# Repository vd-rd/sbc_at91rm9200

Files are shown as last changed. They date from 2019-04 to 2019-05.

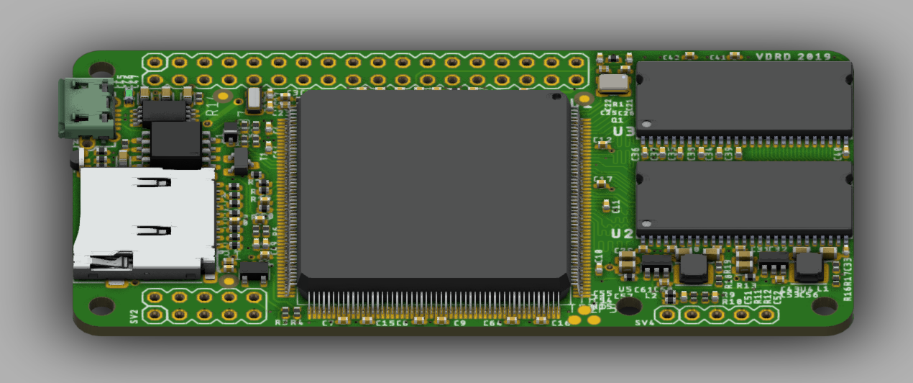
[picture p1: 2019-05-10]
assets/front_ang.PNG

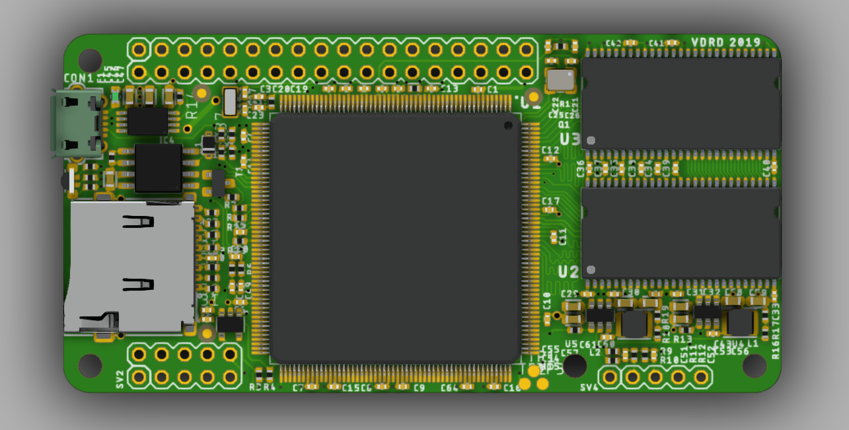
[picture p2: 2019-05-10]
assets/top.PNG

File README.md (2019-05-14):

## Overview
This module, based on Microchip (Atmel) AT91RM9200 microprocessor, is intended as a learning exercise in designing an embedded Linux development board suitable for IoT and other applications.
 All the board resources and documentation are open source and can be contributed to.
 Detailed documentation, as well as resources used can be found in the [docs](docs) and [resources](resources) folders.

### Key features
 * Low price for an embedded Linux system;
 * Medium difficulty to assemble at home;
 * Documented features and mainline support in kernel.

### Specifications
  * AT91RM9200 microprocessor @ 190MHz;
  * 64MB SDRAM @ 90MHz;
  * 2MB DataFlash memory for U-boot and environment storage;
  * MicroSD connector for RootFS and user storage;
  * Expansion headers with common functions available (USART, SPI, I2C, RMII, USB Host, etc.);
  * USB client connector.

### Todo
 * build the board
 * gather the components
 * test the board
 * build optimised U-Boot and Busybox

### Resources
You can find all necesary information to build or evaluate the module here:
   - [View layout and schematic](https://cadlab.io/project/1679) ;
   - [View 3D board render](https://a360.co/2G43pcl);
   - [Fabrication files](https://github.com/vd-rd/sbc_at91rm9200/releases);

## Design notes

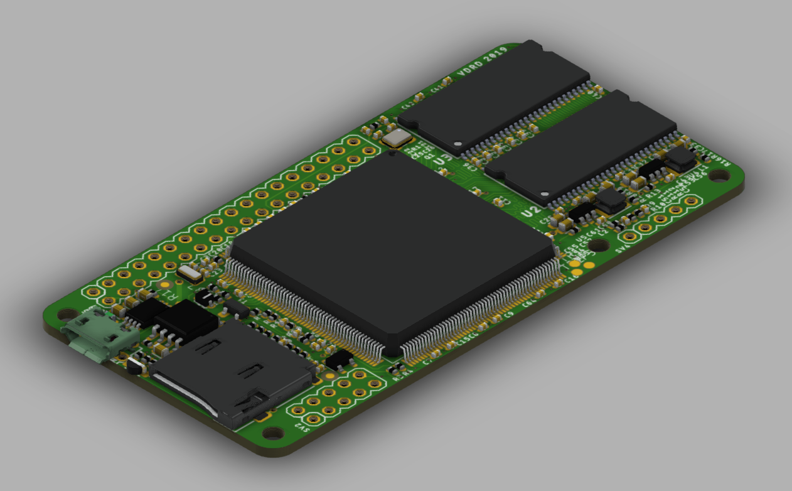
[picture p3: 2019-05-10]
assets/persp.PNG

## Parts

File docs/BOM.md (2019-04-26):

## Revision 0.1 BOM

| # | Part count | Part desciptor | Part name | Part type | Part description | Observations |
| --- | --- | --- |--- | --- | --- | --- |
| 1 | 1 | U1 | AT91RM9200-QU-002 | IC |
| 2 | 2 | U2, U3 | W9825G6KH-6 | IC |
| 3 | 2 | U4, U5 | AP65211A | IC |
| 4 | 1 | U6 | STM1831 | IC |
| 5 | 1 | U7 | AT45DB161 | IC |
| 6 | 1 | CON1 | 10118194 | CONN | Micro USB receptacle |
| 7 | 1 | Q1 |  3225-18.432M-SR | CRYSTAL | 18.432 MHz Crystal |
| 8 | 1 | Q2 | CFPX-217-NHT | CRYSTAL | 32.768 kHz Crystal |
| 9 | 2 | L1, L2 | DJNR3015-4R7 | INDUCTOR | | Actual value TBD |
| 10 | 1 | CON2 | 112J-TXAR | CONN | MicroSD connector |

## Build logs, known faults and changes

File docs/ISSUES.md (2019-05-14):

## Known issues
The processor has some known issues, outlined in the errata section. The most important ones are:
 * The MCI controller (manages the SD Card) 
 * The EBI controller (manages the SDRAM inteface)
 
 ## Hardware limitations
  * SDRAM devices larger than 256Mb can't be used
  * SD Cards maximum supported size should be determined
  * Code on the NVM memory must be loaded outside the device for now ( no method for in system programming)

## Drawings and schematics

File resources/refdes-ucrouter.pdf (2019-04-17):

# AT91RM9200 208-PQFP

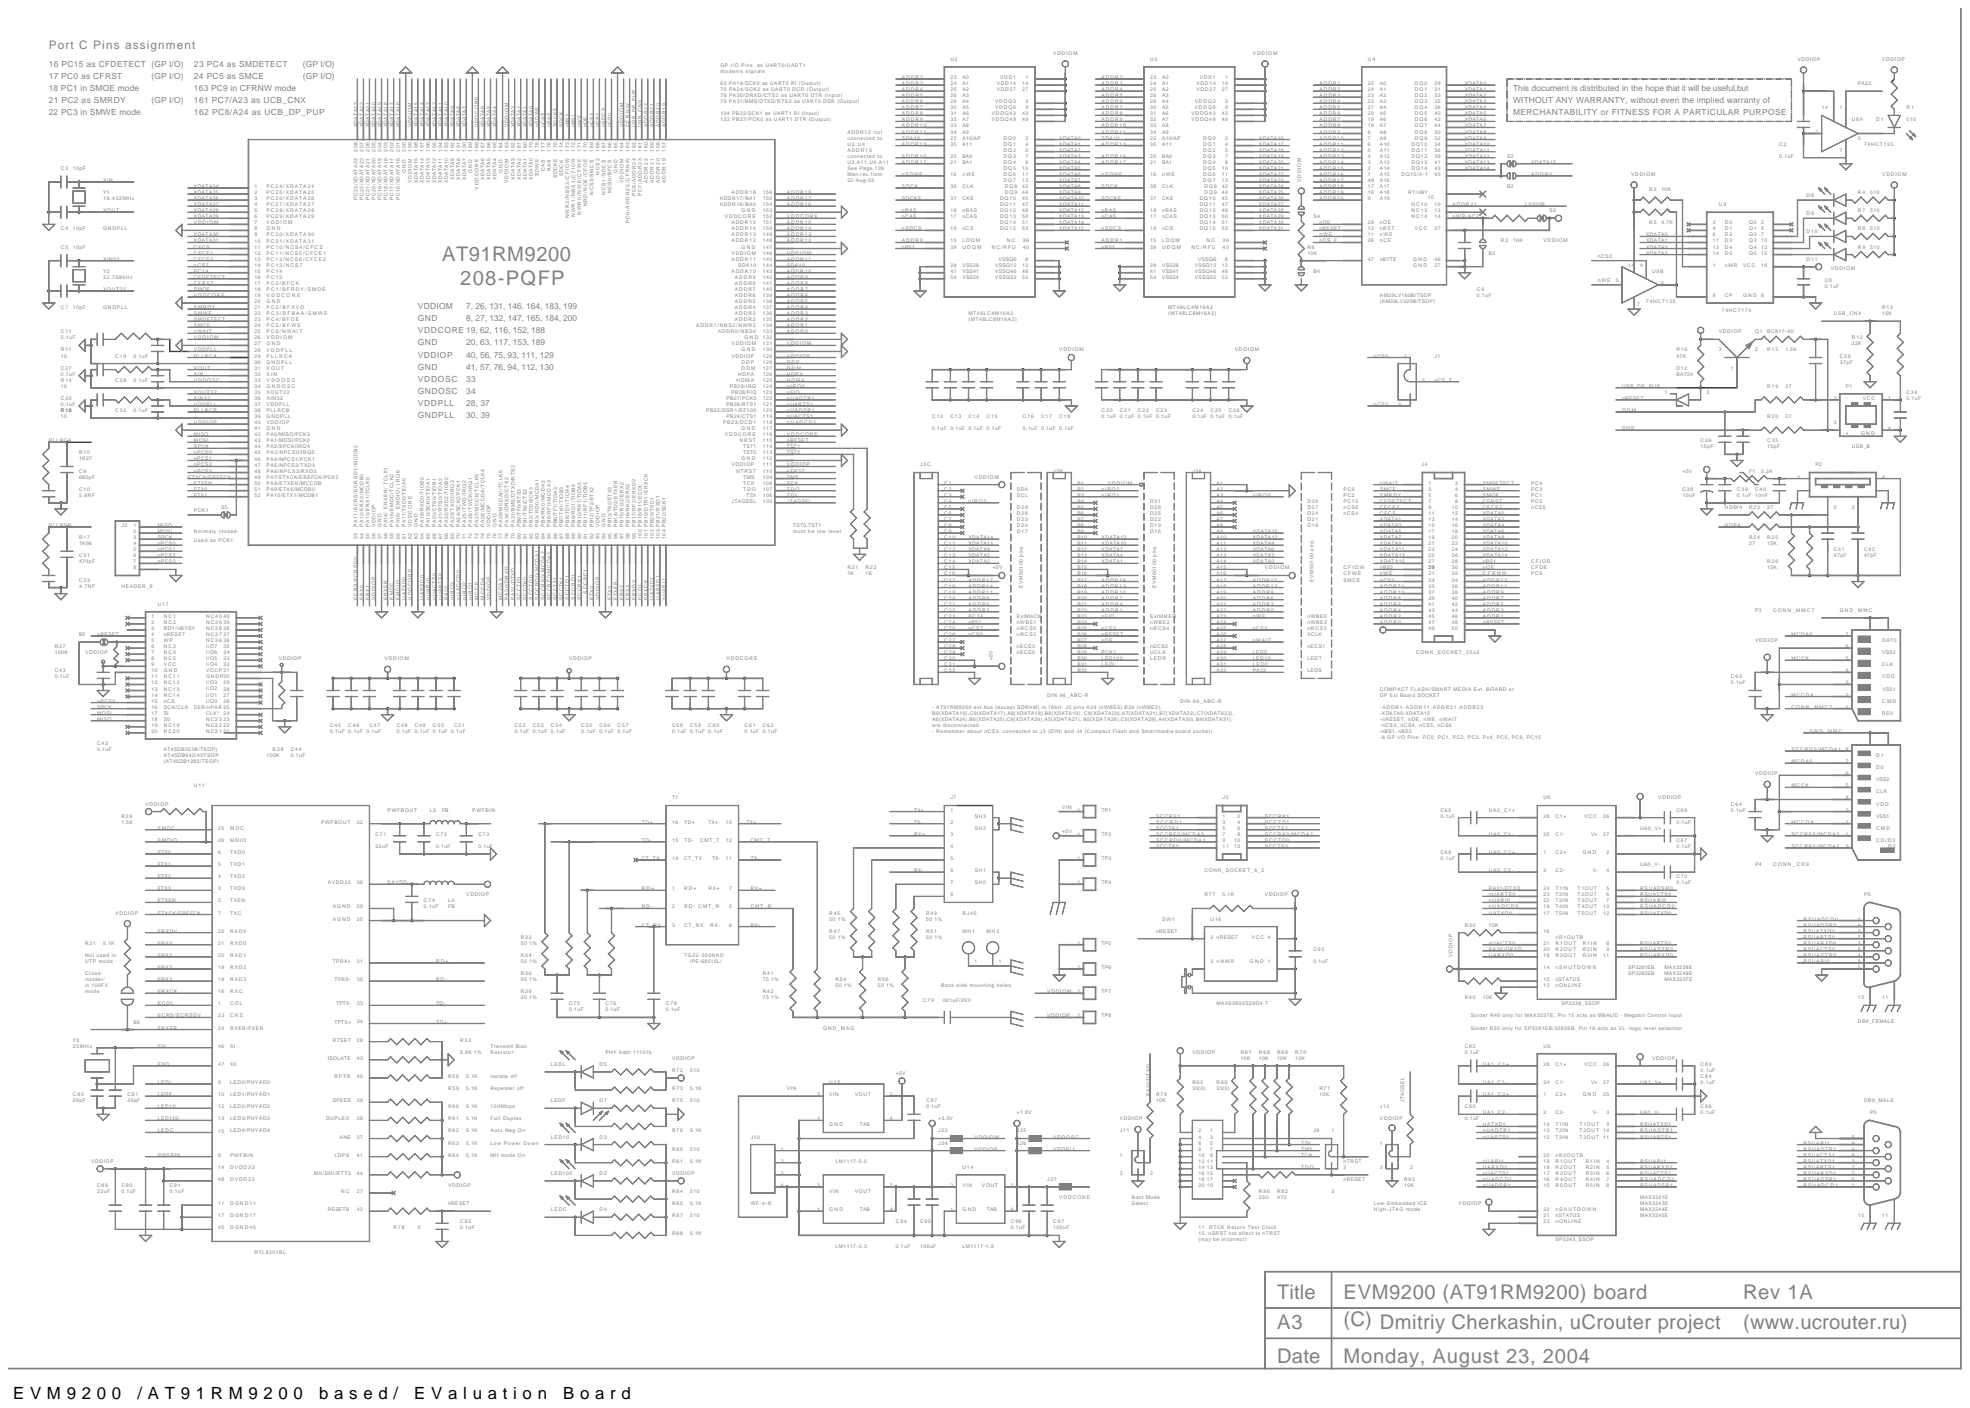
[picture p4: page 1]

65 PA19/SCK0 as UART0 RI (Output)
70 PA24/SCK2 as UART0 DCD (Output)
78 PA30/DRXD/CTS2 as UART0 DTR (Input)
79 PA31/BMS/DTXD/RTS2 as UART0 DSR (Output)

This document is distributed in the hope that it will be useful,but
WITHOUT ANY WARRANTY, without even the implied warranty of

MERCHANTABILITY or FITNESS FOR A PARTICULAR PURPOSE

TST0,TST1
must be low level

COMPACT FLASH/SMART MEDIA Ext. BOARD or
GP Ext Board SOCKET

- AT91RM9200 ext.bus (except SDRAM) is 16bit: J3 pins A24 (nWBE3),B24 (nWBE2),
B9(XDATA16),C9(XDATA17),A8(XDATA18),B8(XDATA19), C8(XDATA20),A7(XDATA21),B7(XDATA22),C7(XDATA23),
A6(XDATA24),B6(XDATA25),C6(XDATA26),A5(XDATA27), B5(XDATA28),C5(XDATA29),A4(XDATA30),B4(XDATA31),
are disconnected
- Remember about nCS3, connected to J3 (DIN) and J4 (Compact Flash and Smartmedia board socket)

TX+CMT_T TX- RX+ CMT_R RX- TD+ TD- CT_TX RD+ RD- CT_RX

Back side mounting holes.

Solder R40 only for MAX3237E, Pin 15 acts as MBAUD - Megabit Control Input

Solder R30 only for SP3281EB/3282EB, Pin 16 acts as VL -logic level selection

11. RTCK Return Test Clock
15. nSRST not affect to nTRST
(may be incorrect)

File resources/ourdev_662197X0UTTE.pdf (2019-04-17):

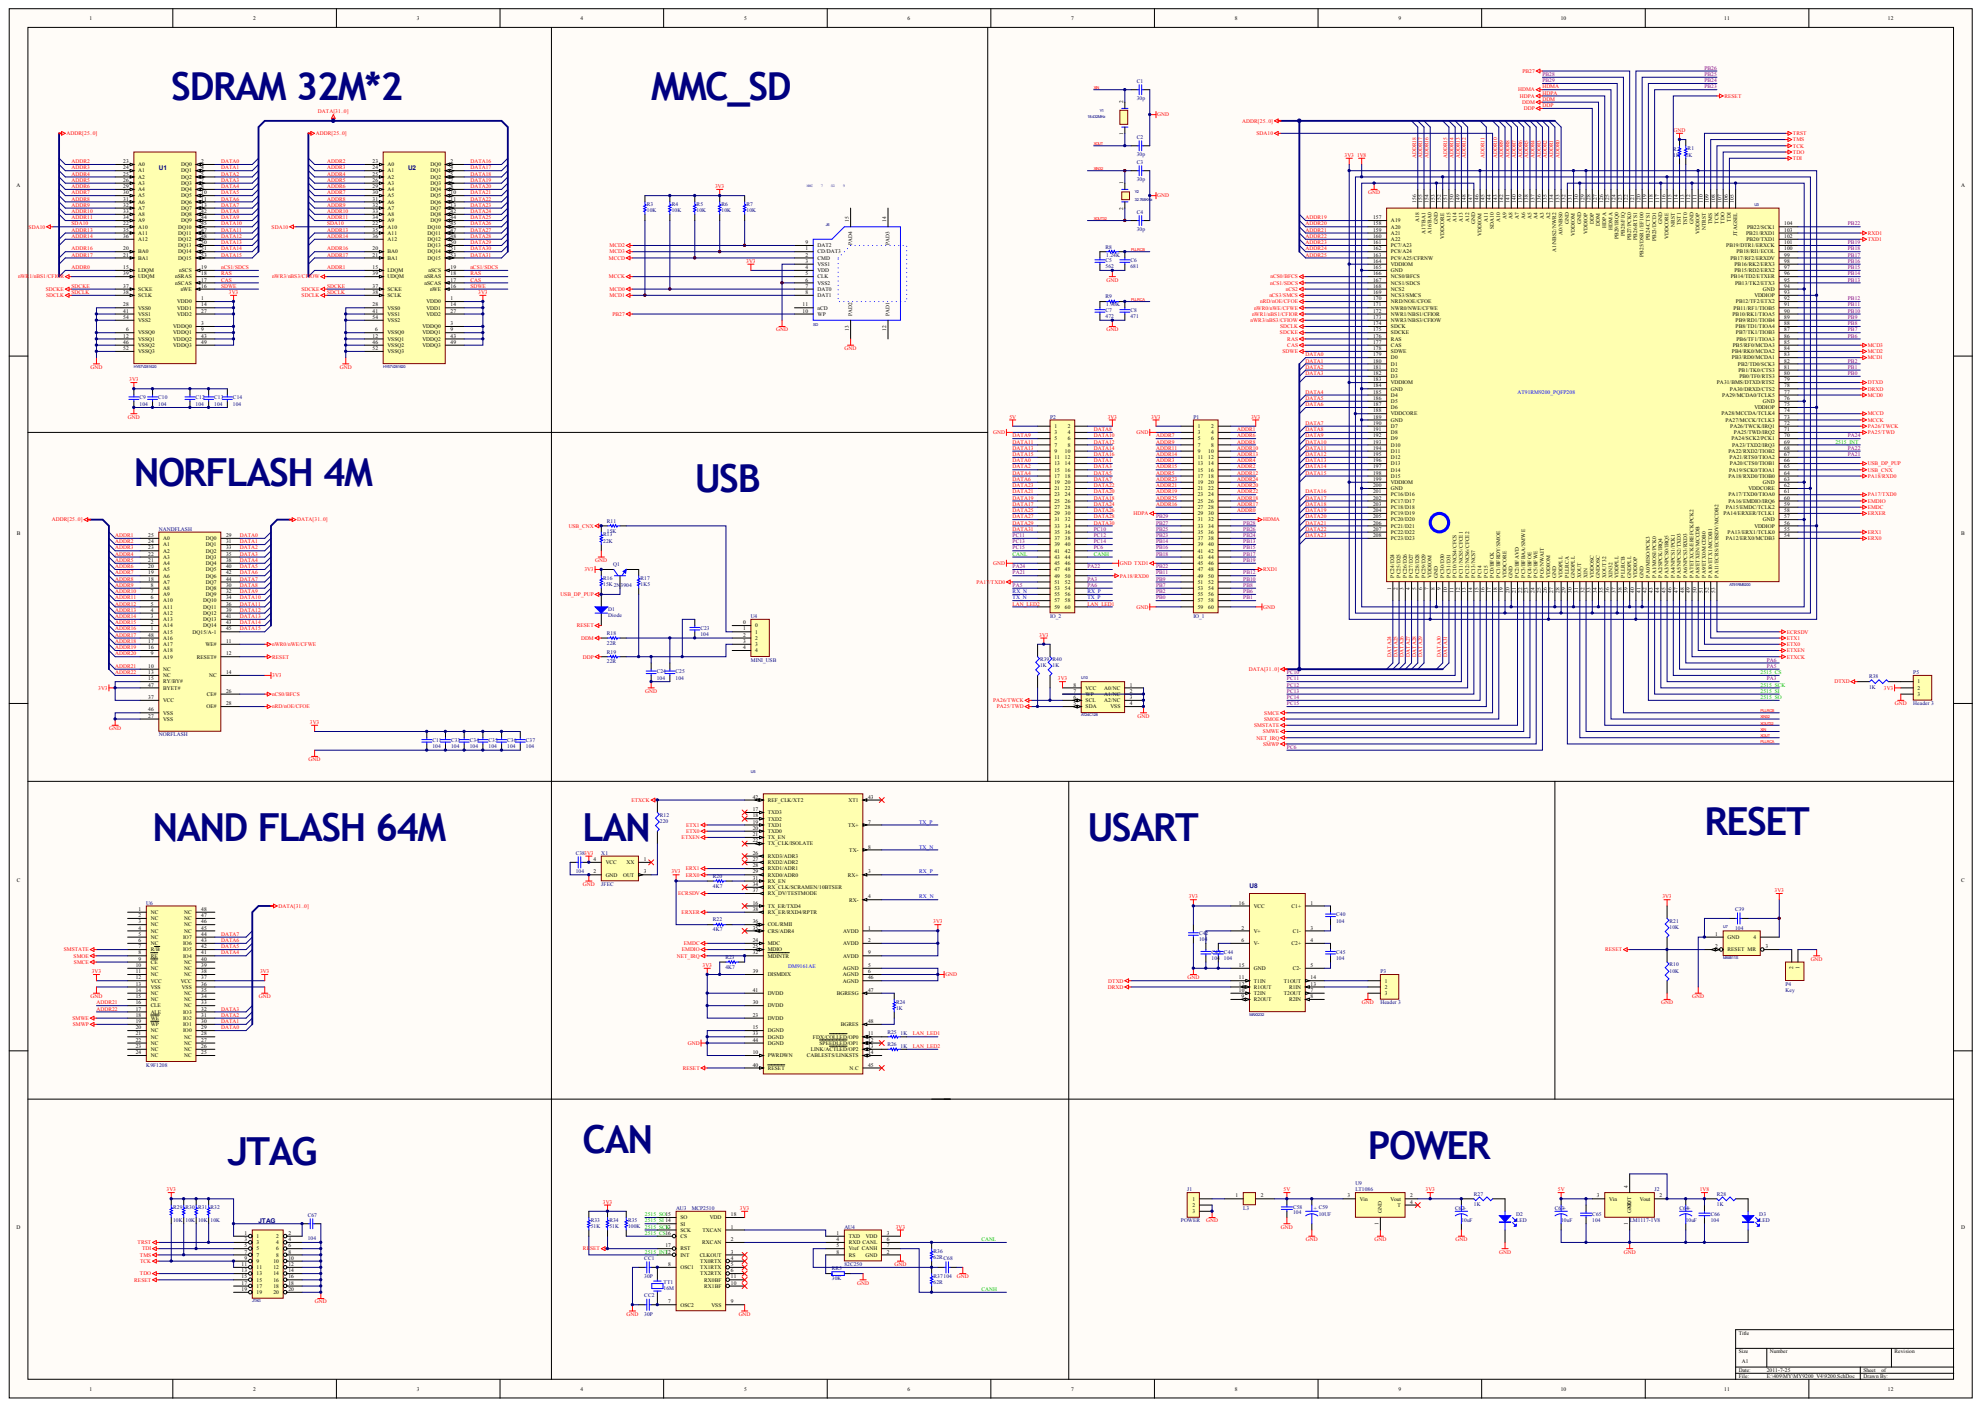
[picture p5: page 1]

HDMA | PB23
HDPA DDM | GND

JTAGSEL 105 TDI 106 TDO 107 TCK 108 TMS 109 NTRST 110 VDDIOP 111 GND 112 TST0 113 TST1 114 NRST 115 VDDCORE 116 GND 117 PB23/DCD1 118 PB24/CTS1 119 PB25/DSR1/EF100 120 PB26/RTS1 121 PB27/PCK0 122 PB28/FIQ 123 PB29/IRQ0 124 HDMA 125 HDPA 126 DDM 127 DDP 128 VDDIOP 129 GND 130 VDDIOM 131 GND 132 A0/NBS0 133 A1/NBS2/NWR2 134 A2 135 A3 136 A4 137 A5 138 A6 139 A7 140 A8 141 A9 142 A10 143 SDA10 144 A11 145 VDDIOM 146 GND 147 A12 148 A13 149 A14 150 A15 151 VDDCORE 152 GND 153 A16/BA0 154 A17/BA1 155 A18 156

DATA3 DATA4 | D3 182 VDDIOM 183

DATA5 | D5 186

Bill of Materials | <Parameter Title not found>
Source Data From: | 9200.PrjPCB
Project: | | 9200.PrjPCB
Variant: | | None
Creation Date: 2011-7-25 | 17:10:50
Print Date: | 40749 | 40749.71593
Footprint | Comment | LibRef | Designator | Description | Quantity
MCP2515 | MCP2510 | MCP2510 | AU3 | | 1
SO-8 | 82C250 | 82C250 | AU4 | | 1
0603 | Cap | Cap | C1, C2, C3, C4, C5, C6, C7, C8, C67 | Capacitor | 9
0603 | 104 | Cap | C9, C10, C11, C12, C13, C14, C23, C24,
| | | C25, C33, C34, C35, C36, C37, C38, C39,
| | | C40, C42, C43, C44, C45, C58, C65, C66,
| | | C68 | Capacitor | 25
TAN_CAP | 10UF | CAPACITOR
| | POL | C59, C62, C63, C64 | Capacitor | 4
0603 | 30P | CAP | CC1, CC2 | Capacitor | 2
1206 | Diode | Diode | D1 | Default Diode | 1
0805 | LED | LED | D2, D3 | | 2
POWER | POWER | CON3 | J1 | Connector | 1
SOT223 | LM1117-1V8 | LM1117-1V5 | J2 | | 1
SD_CARD | SD_MMC_CAR
| D2 | SD_MMC_CAR
| | D2 | J6 | | 1
FKV20SN | JTAG | MULTI_ICE | JTAG | | 1
L | Component_1 | Component_1 | L3 | | 1
NANDFLASH | NORFLASH | NORFLASH | NANDFLASH | | 1
IDC60 | IO_1 | Header 30X2 | P1 | Header, 30-Pin, Dual row | 1
IDC60 | IO_2 | Header 30X2 | P2 | Header, 30-Pin, Dual row | 1
con3 | Header 3 | Header 3 | P3, P5 | Header, 3-Pin | 2
KEY | Key | Header 2 | P4 | Header, 2-Pin | 1
SOT-23+ | 2N3904 | 2N3904 | Q1 | NPN General Purpose Amplifier | 1
0603 | Res1 | Res1 | R1, R2, R3, R4, R5, R6, R7, R8, R9, R11,
| | | R13, R16, R17, R18, R19, R20, R22, R23,
| | | R24, R25, R26, R29, R30, R31, R32 | Resistor | 25
0603 | 10K | RES1 | R10, R21 | | 2
0603 | 220 | RES1 | R12 | | 1
0603 | 1K | RES1 | R27, R28, R38, R39, R40 | | 5
0603 | 51K | Res1 | R33, R34 | Resistor | 2
0603 | 100K | Res1 | R35 | Resistor | 1
0603 | 62R | Res1 | R36, R37 | Resistor | 2
0603 | 30K | RESISTOR | RR5 | | 1
XTAL | 16M | CRYSTAL | TT1 | Crystal | 1
SDRAM | HY57V281620 | K4S561632C | U1, U2 | | 2
9200 | AT91RM9200 | AT91RM9200P
| | Q208_0 | U3 | | 1
USB_DEVIC E | MINI_USB | MINI_USB | U4 | | 1
DM9161 | DM9161AE | DM9161E_3 | U5 | | 1
NANDFLASH | K9F1208 | NAND_FLASH | U6 | | 1
MAX811S | MAX811S | UD215_0 | U7 | | 1
MAX232 | MAX3232 | max232_1 | U8 | | 1
LTC1086 | LT1086 | LM1117-1V5 | U9 | 1A LOW DROPOUT VOLTAGE
| | | | REGULATOR | 1
SO-8 | AT24C128 | CAT24WC128_0 | U10 | | 1
JFEC | JFEC | JFEC | X1 | | 1
CRYSTAL | 18.432MHz | XTAL3_0 | Y1 | | 1
32768 | 32.768KHz | XTAL1_0 | Y2 | | 1
| | | | | 110
Approved | | Notes

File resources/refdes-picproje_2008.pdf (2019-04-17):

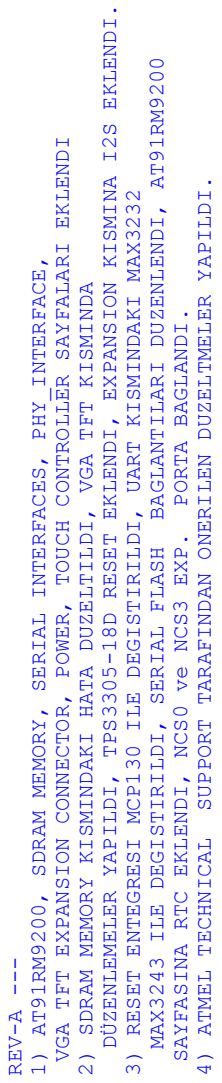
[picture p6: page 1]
Title; 00_REVISION HISTORY A; ARM9SBC; 1 11 Wednesday, February 06, 2008; REV-A ---

Size Document Number Rev

ERDAL T. --- GOKTUG C. --- PICPROJE 2008

Date: Sheet of

DÜZENLEMELER YAPILDI, TPS3305-18D RESET EKLENDI, EXPANSION KISMINA I2S EKLENDI.

MAX3243 ILE DEGISTIRILDI, SERIAL FLASH BAGLANTILARI DUZENLENDI, AT91RM9200

VGA TFT EXPANSION CONNECTOR, POWER, TOUCH CONTROLLER SAYFALARI EKLENDI

4) ATMEL TECHNICAL SUPPORT TARAFINDAN ONERILEN DUZELTMELER YAPILDI.

3) RESET ENTEGRESI MCP130 ILE DEGISTIRILDI, UART KISMINDAKI MAX3232

1) AT91RM9200, SDRAM MEMORY, SERIAL INTERFACES, PHY_INTERFACE,

2) SDRAM MEMORY KISMINDAKI HATA DUZELTILDI, VGA TFT KISMINDA

SAYFASINA RTC EKLENDI, NCS0 ve NCS3 EXP. PORTA BAGLANDI.

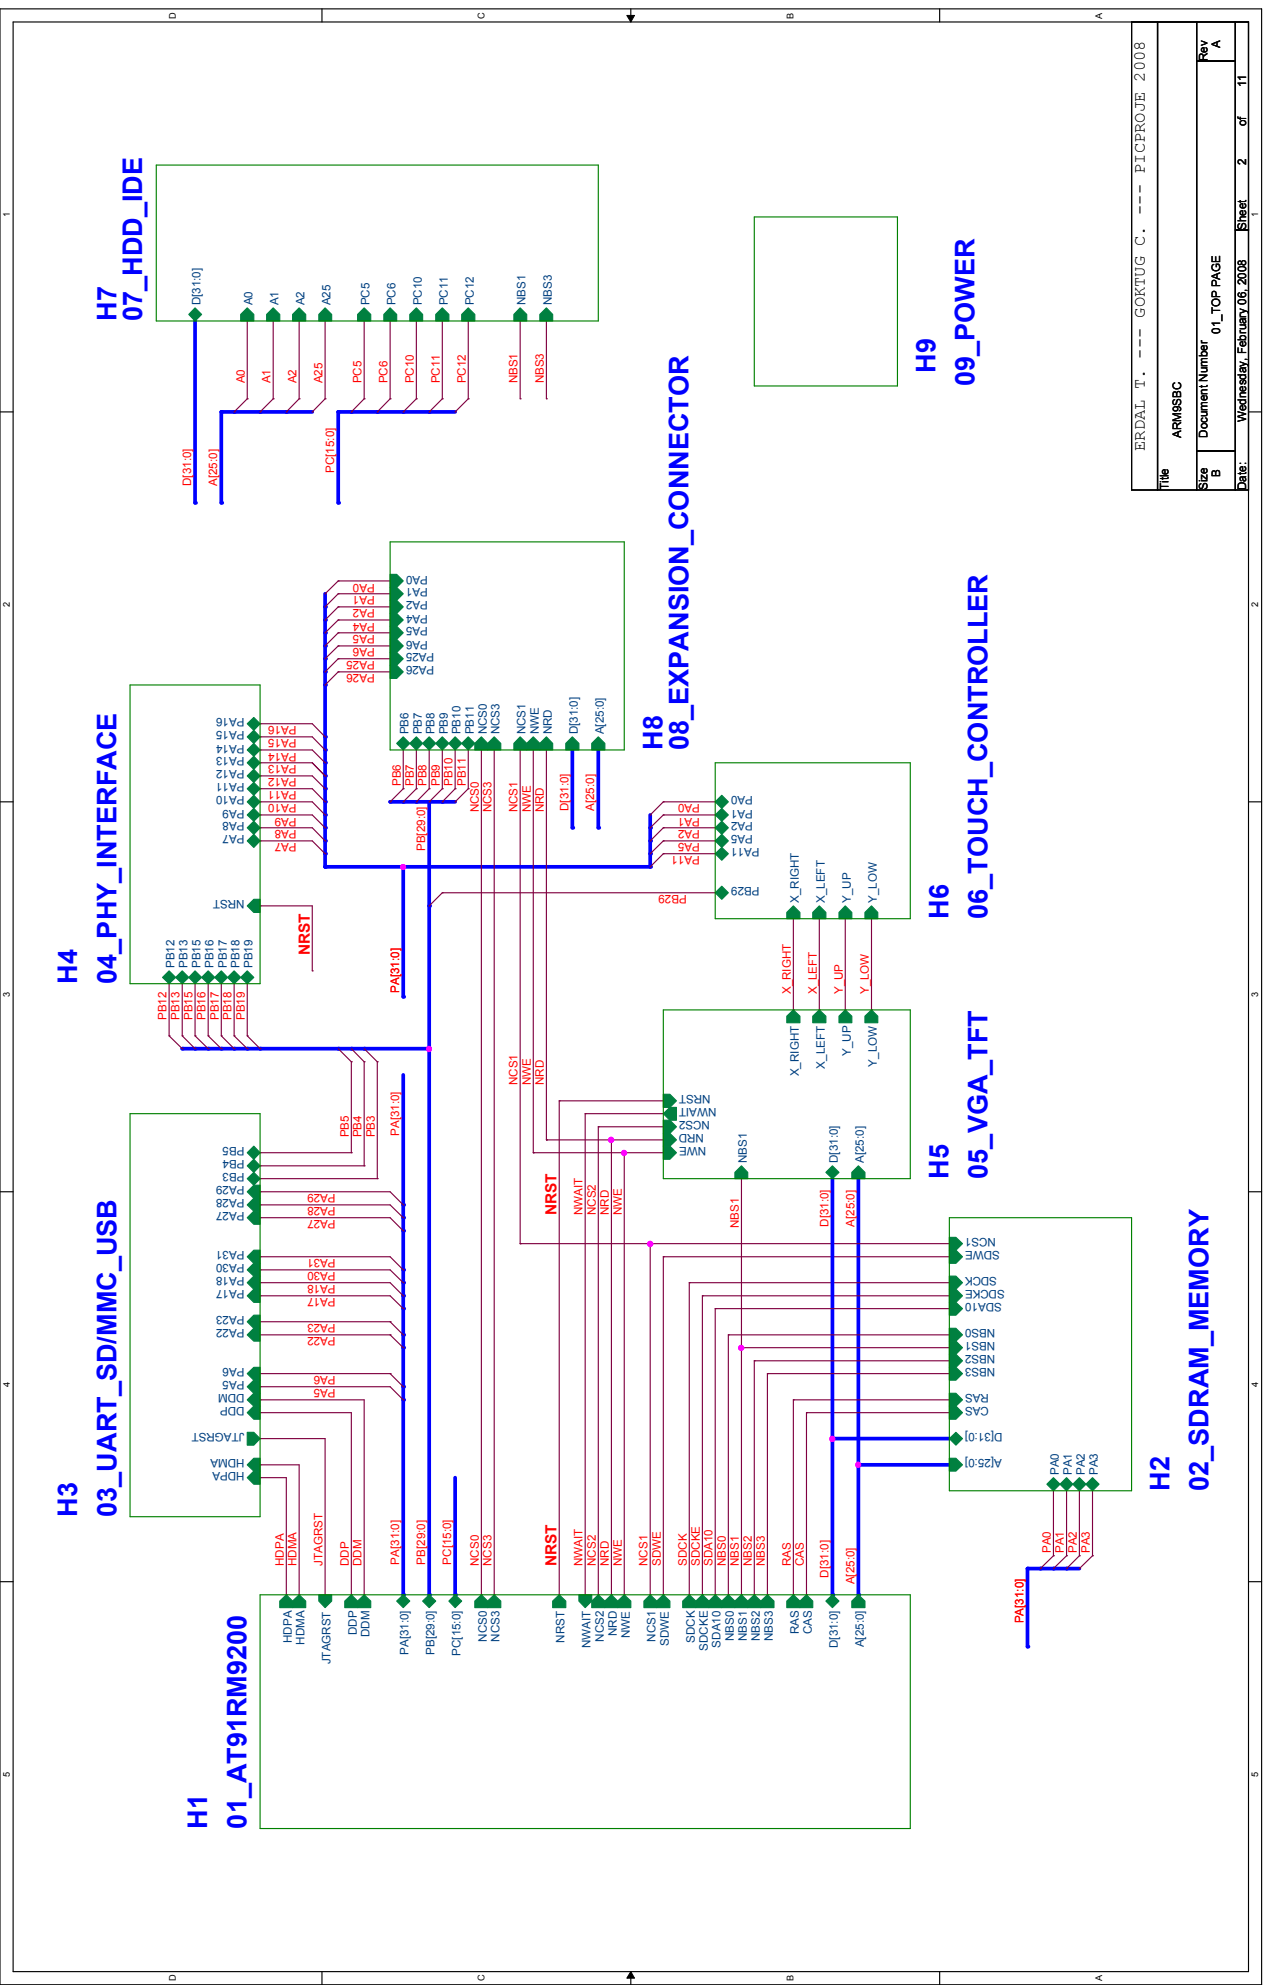
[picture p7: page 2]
HDPA; HDMA; SDWE; SDCK; SDCKE; NBS0; NBS1; RAS; CAS; JTAGRST; DDP; DDM; NRST NRST; NCS2 NCS2; NWAIT NWAIT; NCS1 NCS1; X_RIGHT; X_LEFT; Y_LOW; NCS1; NBS2; NBS3; SDA10; NRST; NRD NRD; NWE NWE; NCS0 NCS0; NCS3 NCS3; Title; 01_TOP PAGE A; ARM9SBC; 2 11 Wednesday, February 06, 2008; NCS2; NWE; NRD; NWAIT; NCS0; NCS3; 03_UART_SD/MMC_USB; 02_SDRAM_MEMORY; 05_VGA_TFT; 06_TOUCH_CONTROLLER; 04_PHY_INTERFACE; 08_EXPANSION_CONNECTOR; 09_POWER; 07_HDD_IDE

ERDAL T. --- GOKTUG C. --- PICPROJE 2008

Size Document Number Rev

Date: Sheet of

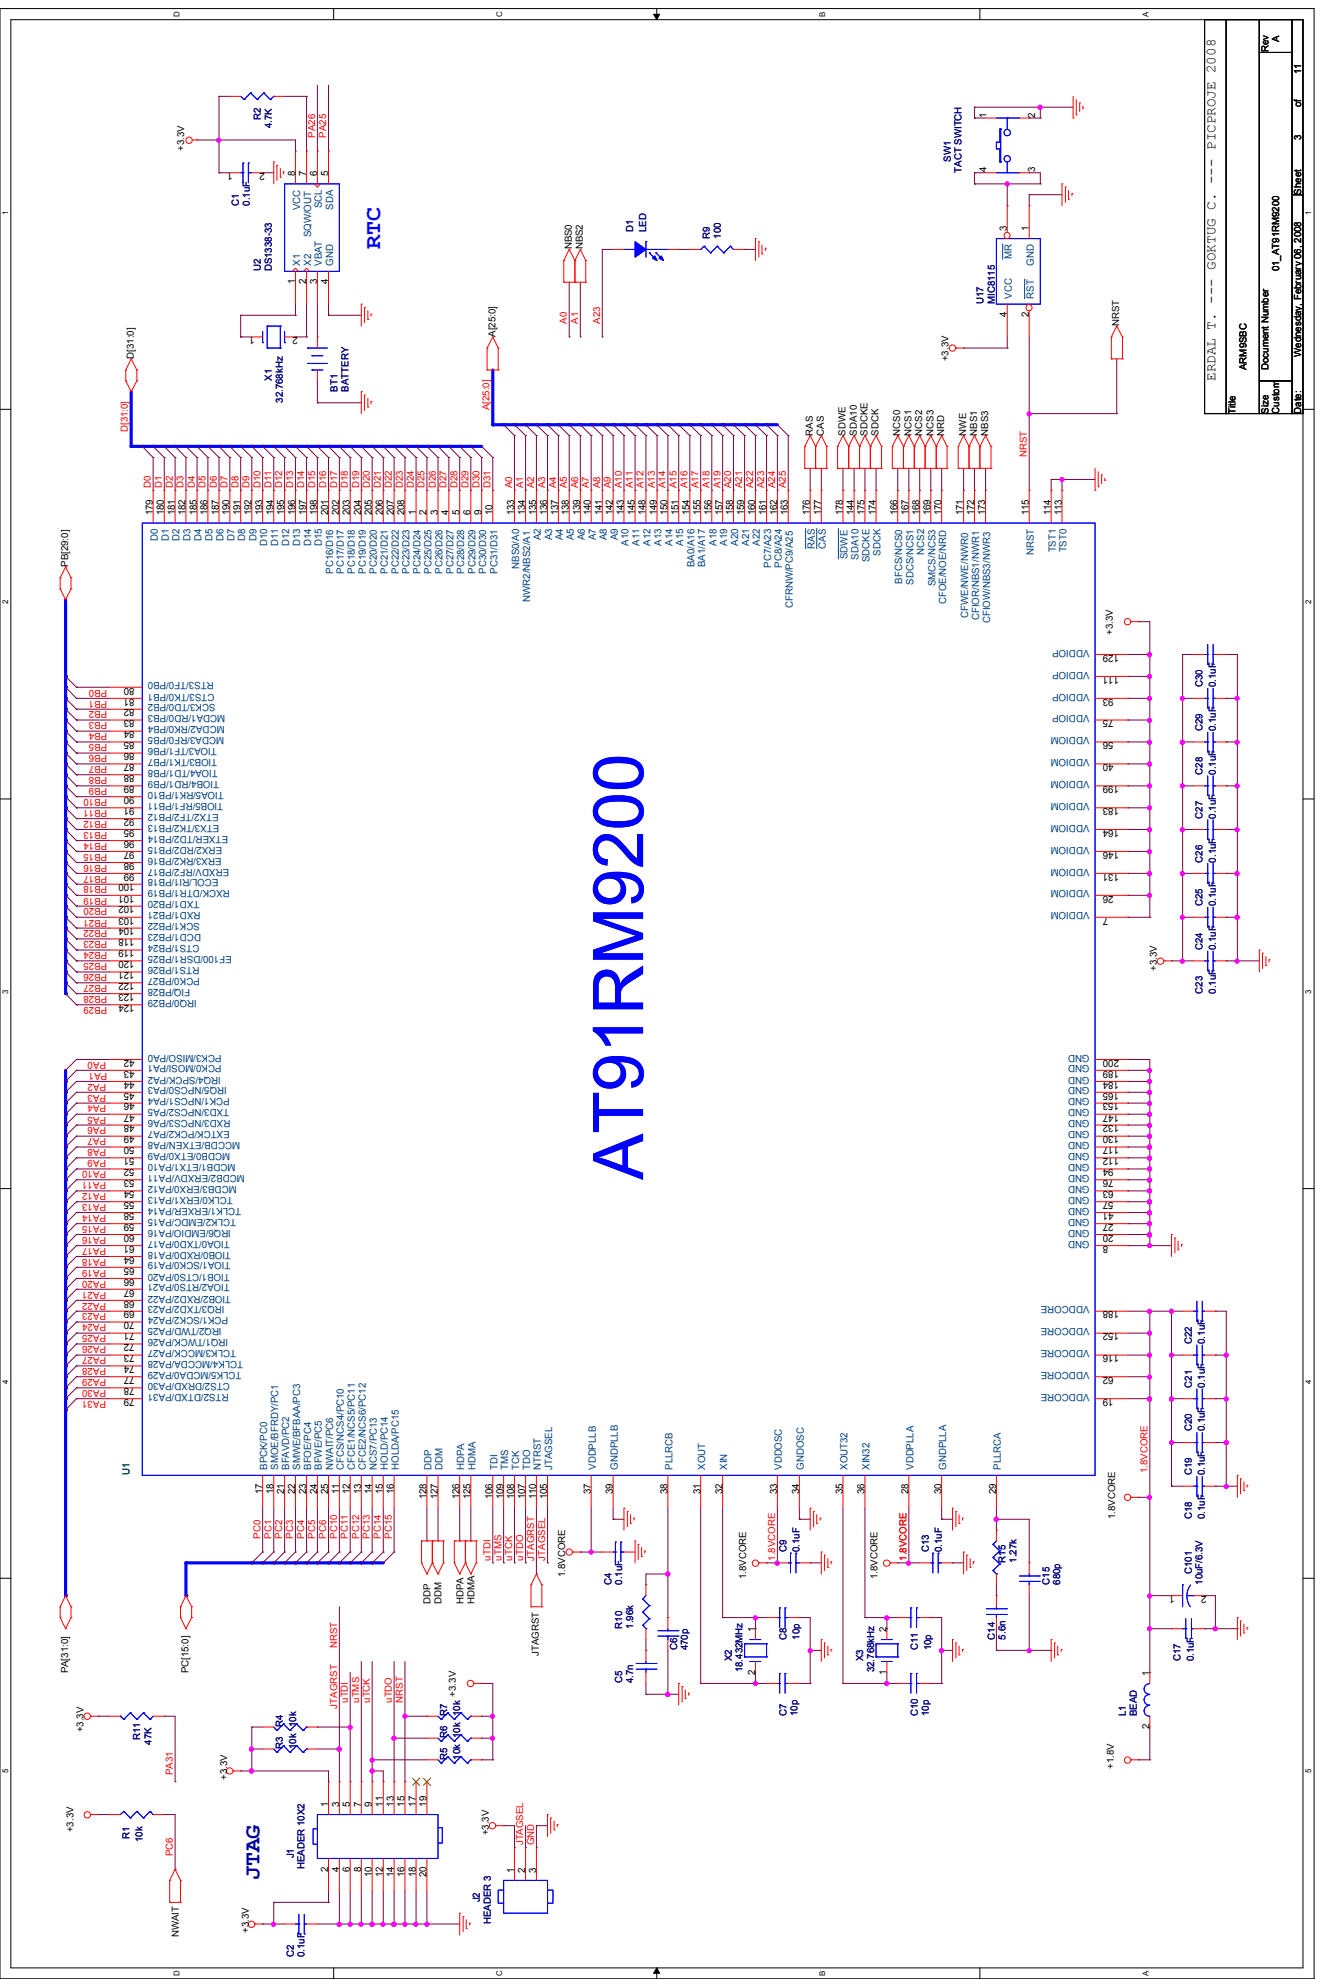
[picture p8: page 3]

Size Document Number Rev

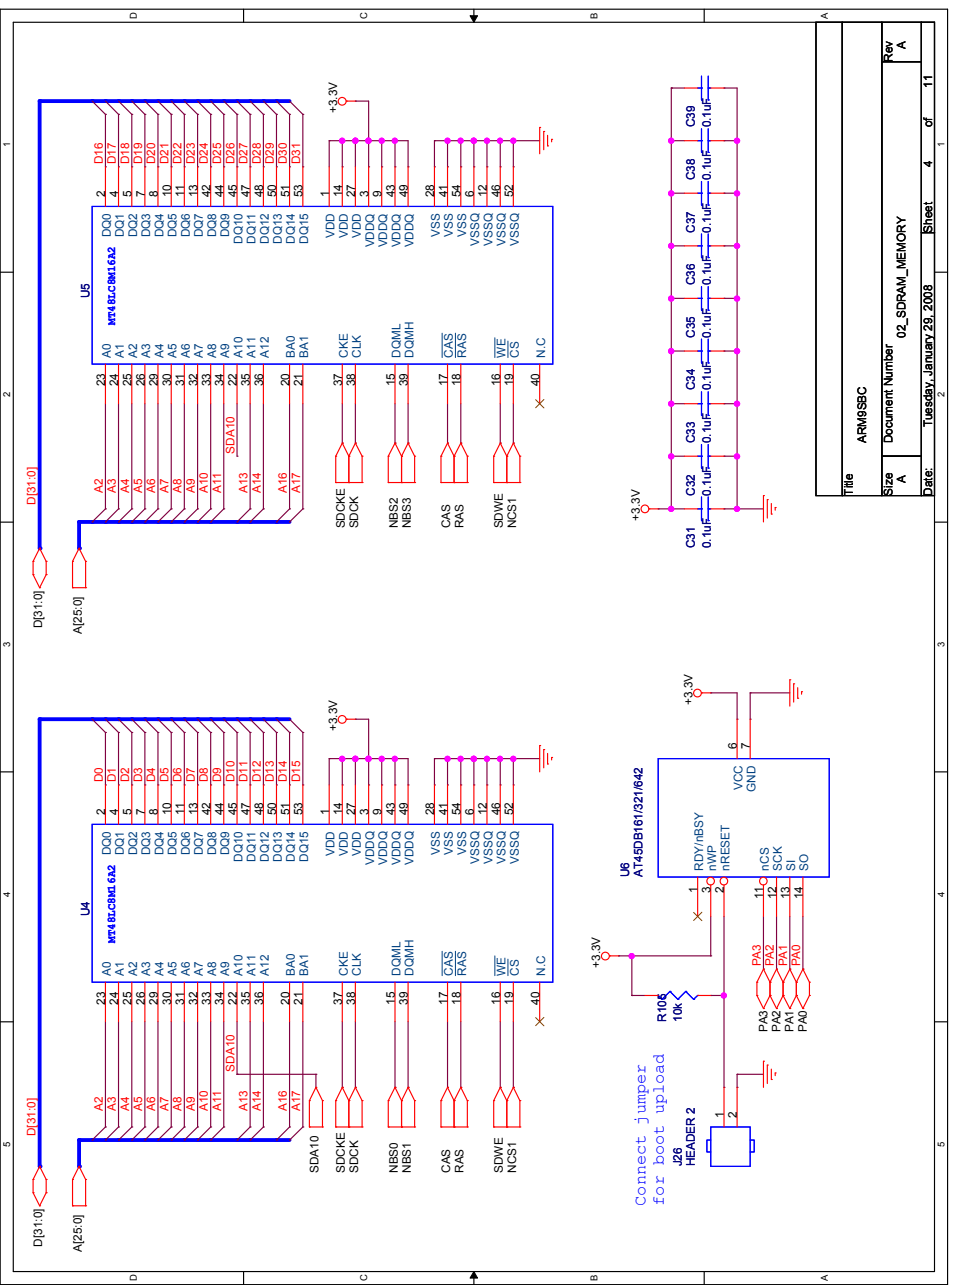
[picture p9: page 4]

Size Document Number Rev

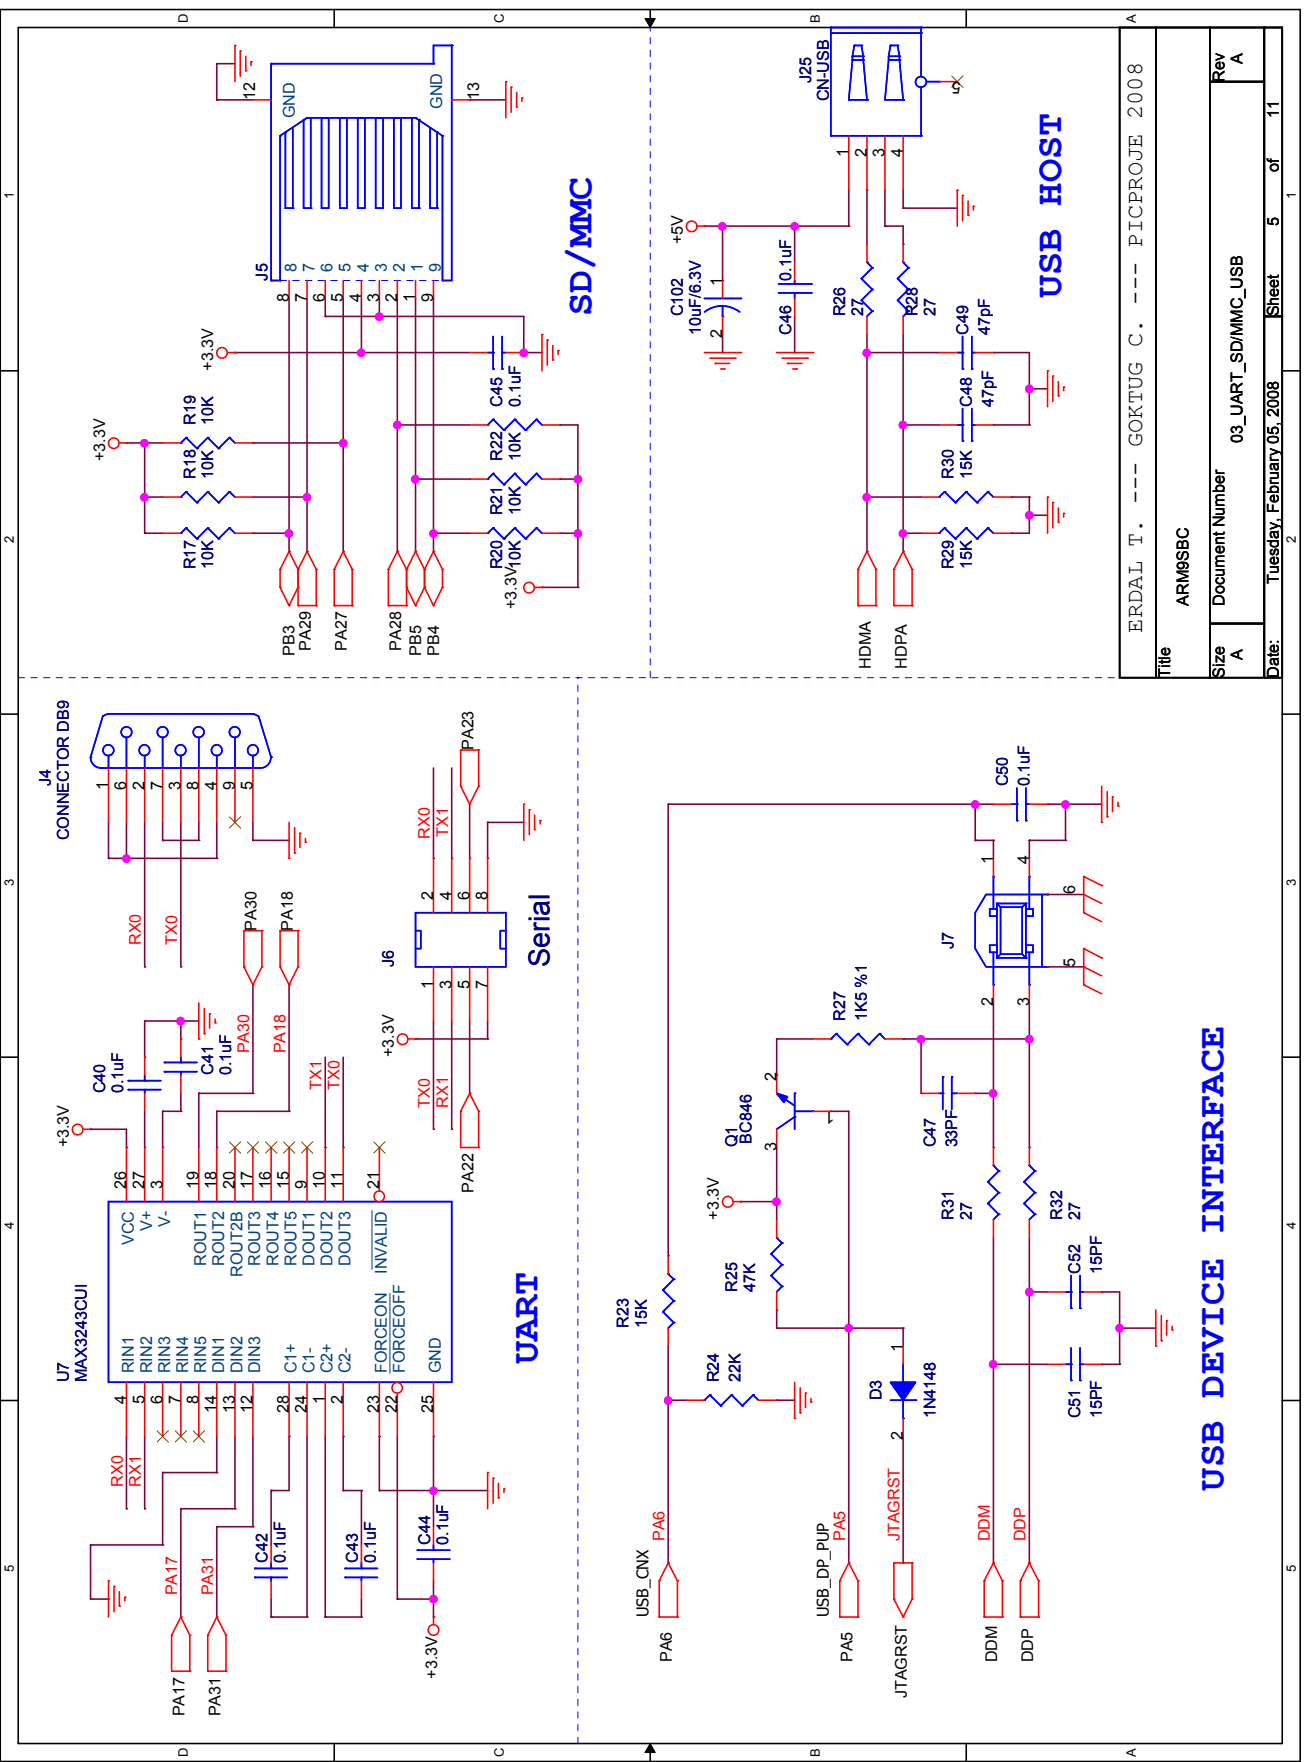
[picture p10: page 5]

Size Document Number Rev

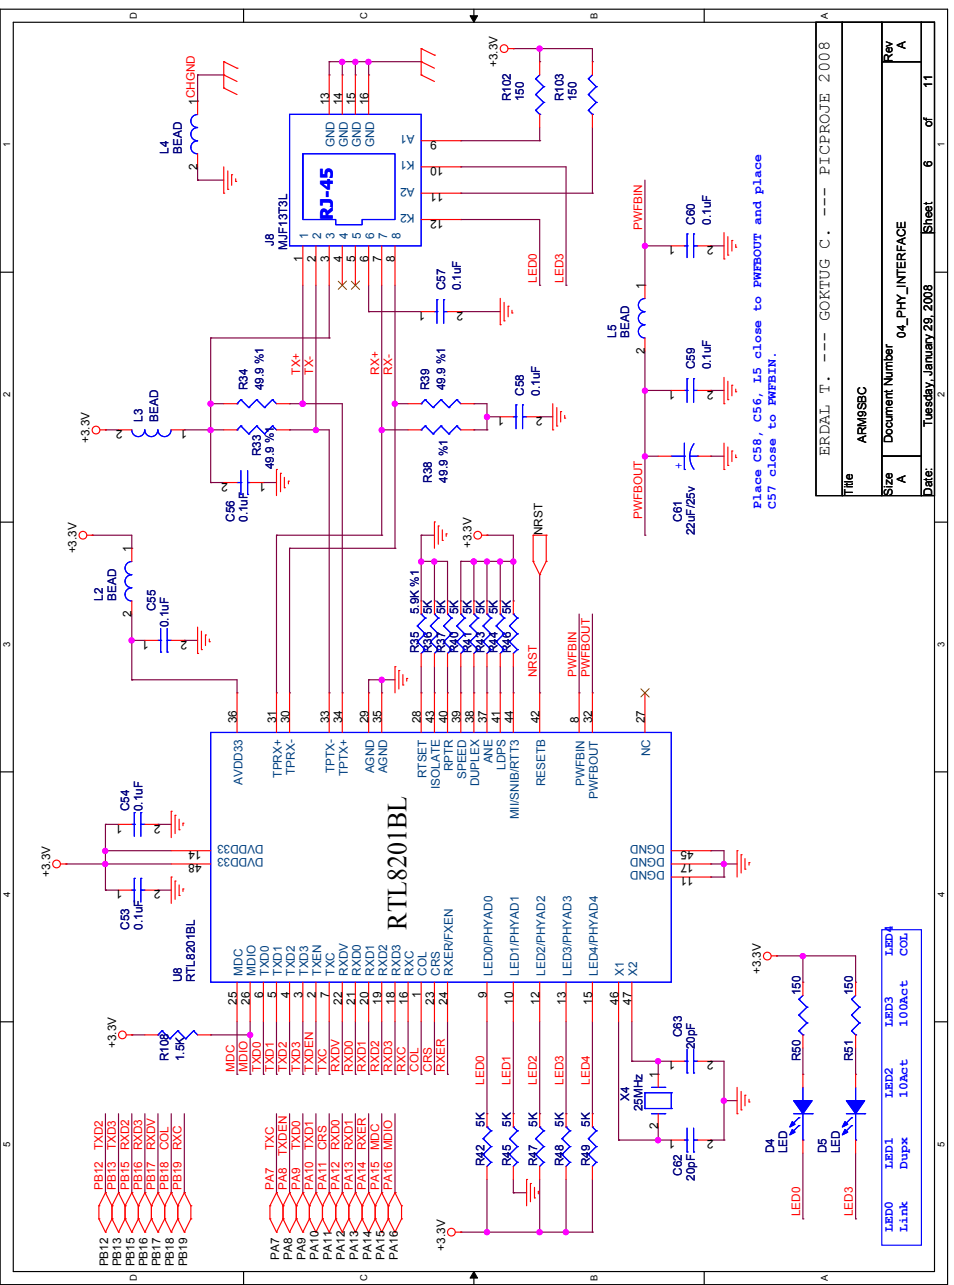
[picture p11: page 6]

Size Document Number Rev

CHGND MDC TXD0 TXD1 TXD2 TXD3 TXDEN TXC RXDV RXD0 RXD1 RXD2 RXD3

Place C58, C56, L5 close to PWFBOUT and place

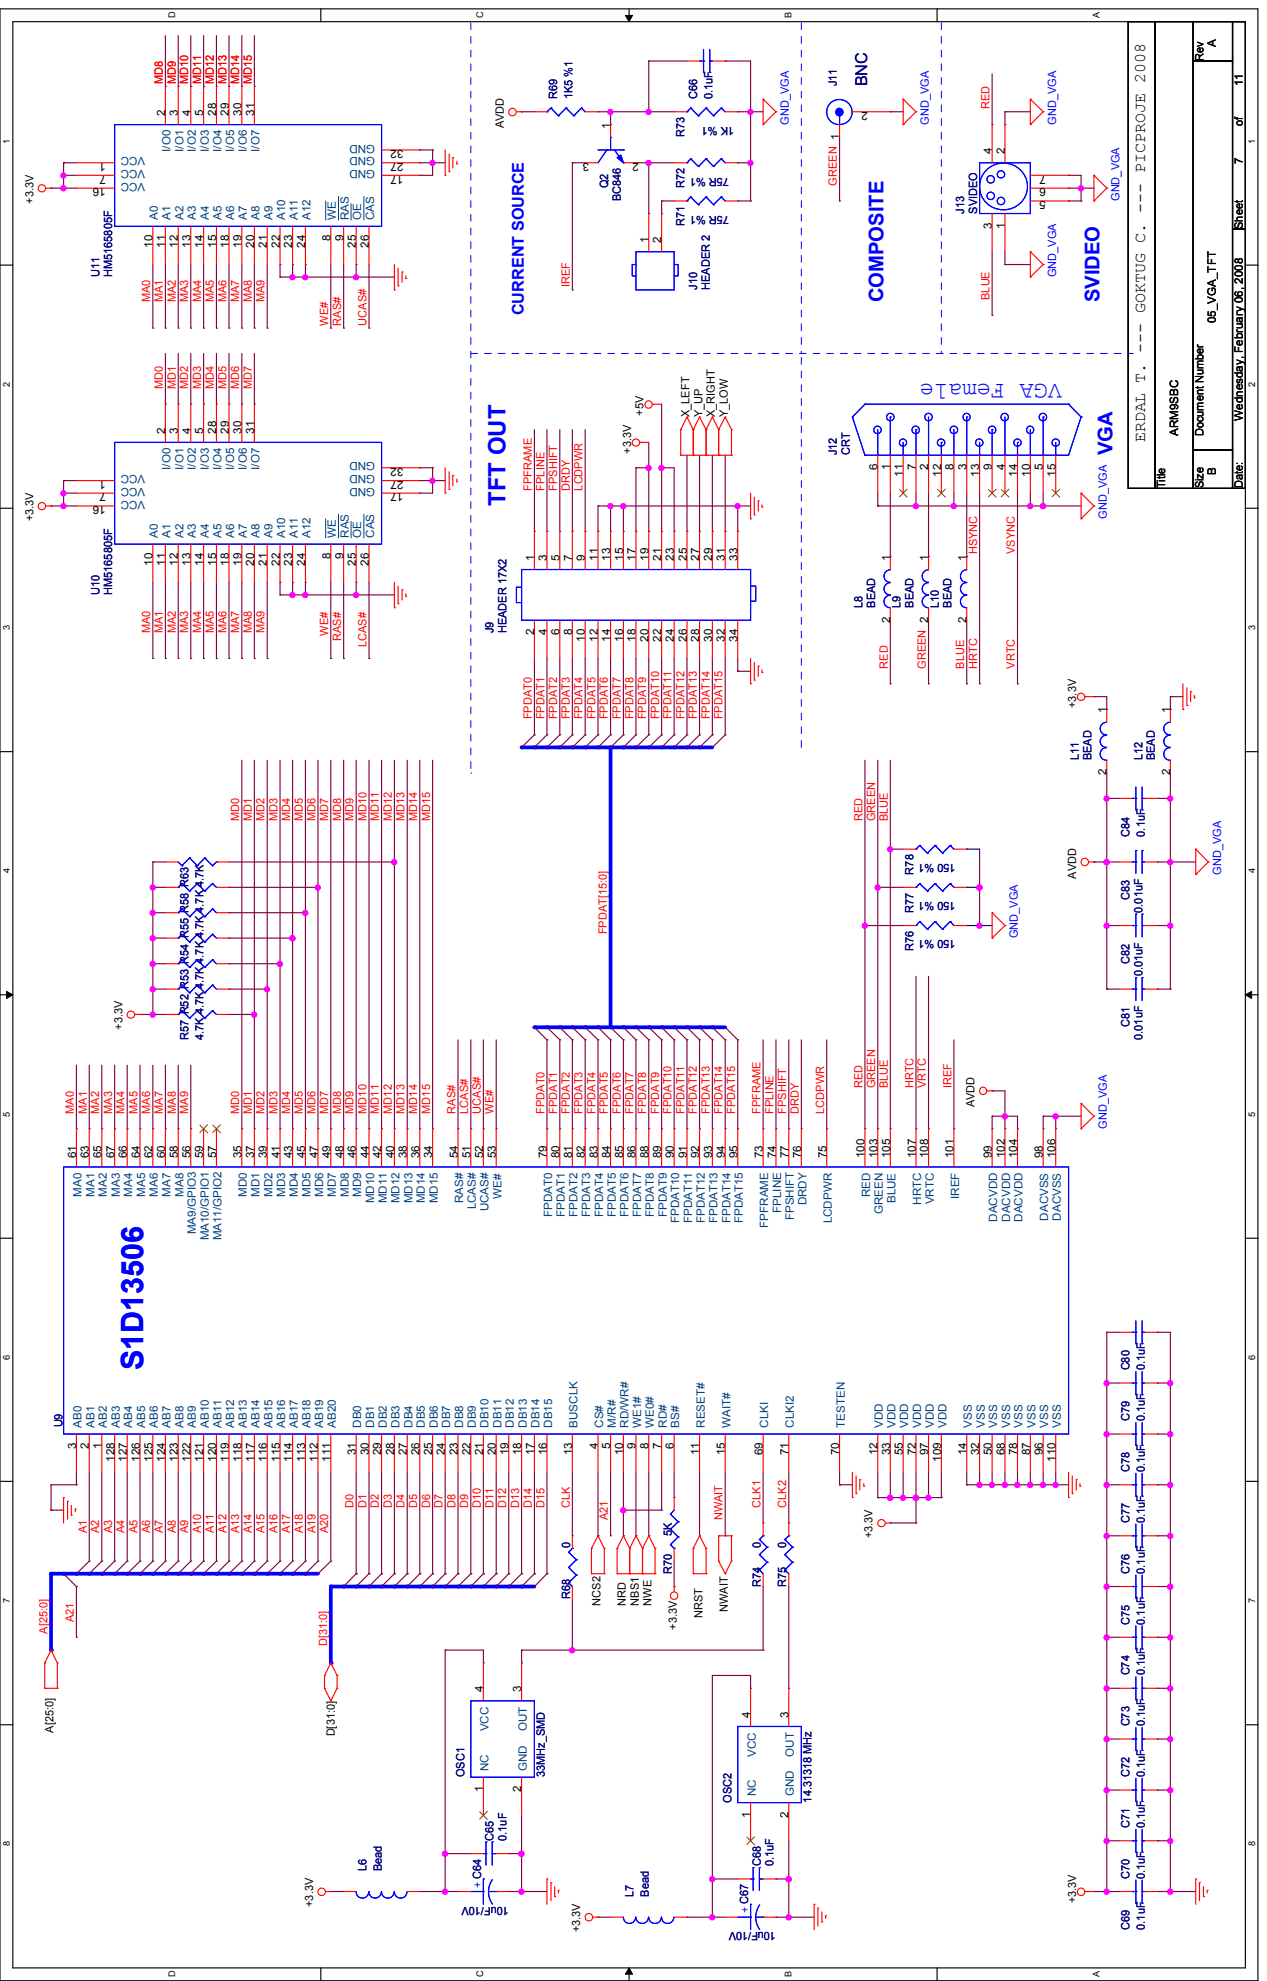
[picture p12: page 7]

Size Document Number Rev

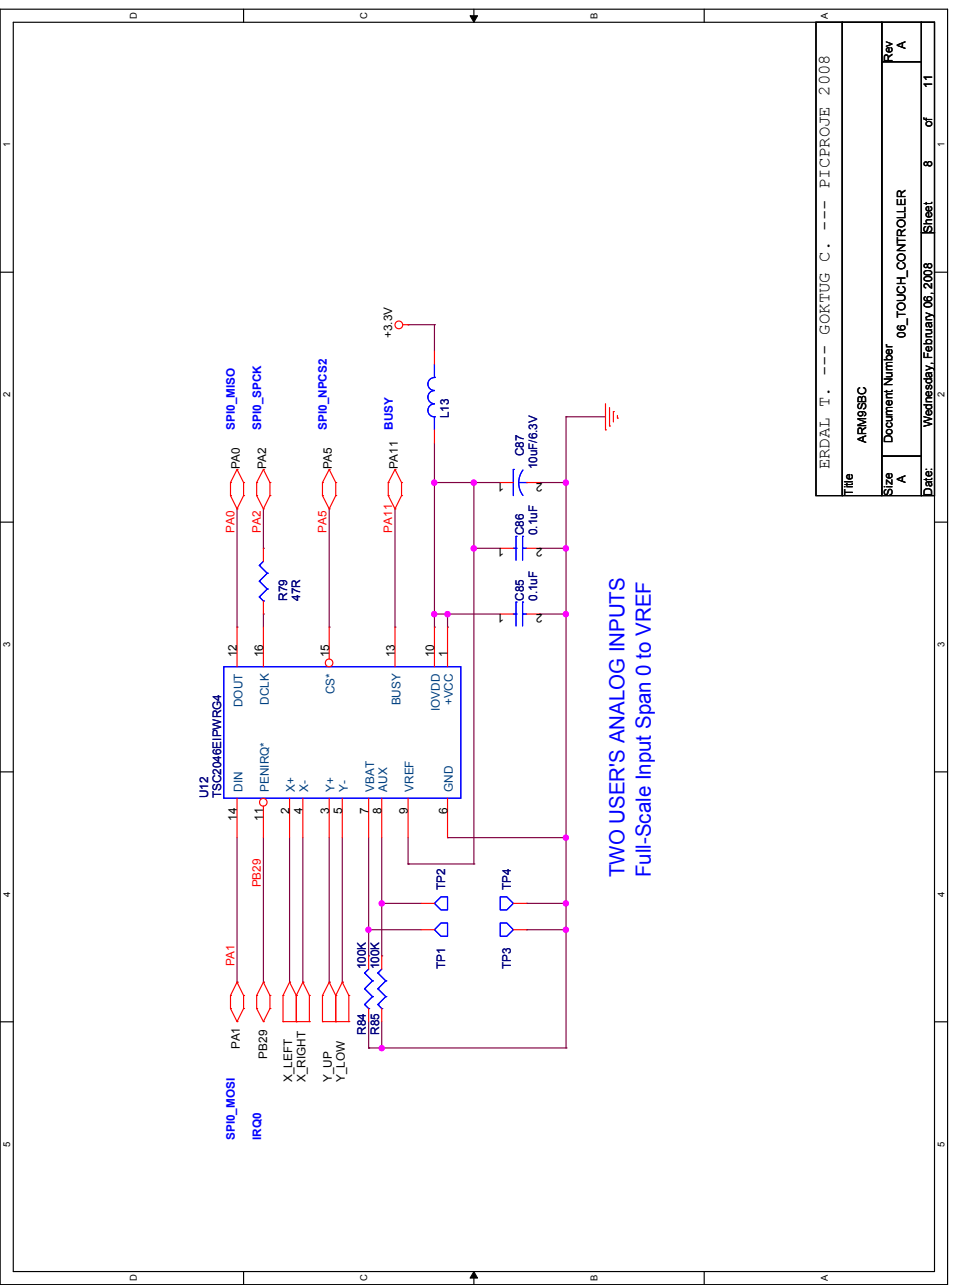
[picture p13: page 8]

Size Document Number Rev

TWO USER'S ANALOG INPUTS

Full-Scale Input Span 0 to VREF

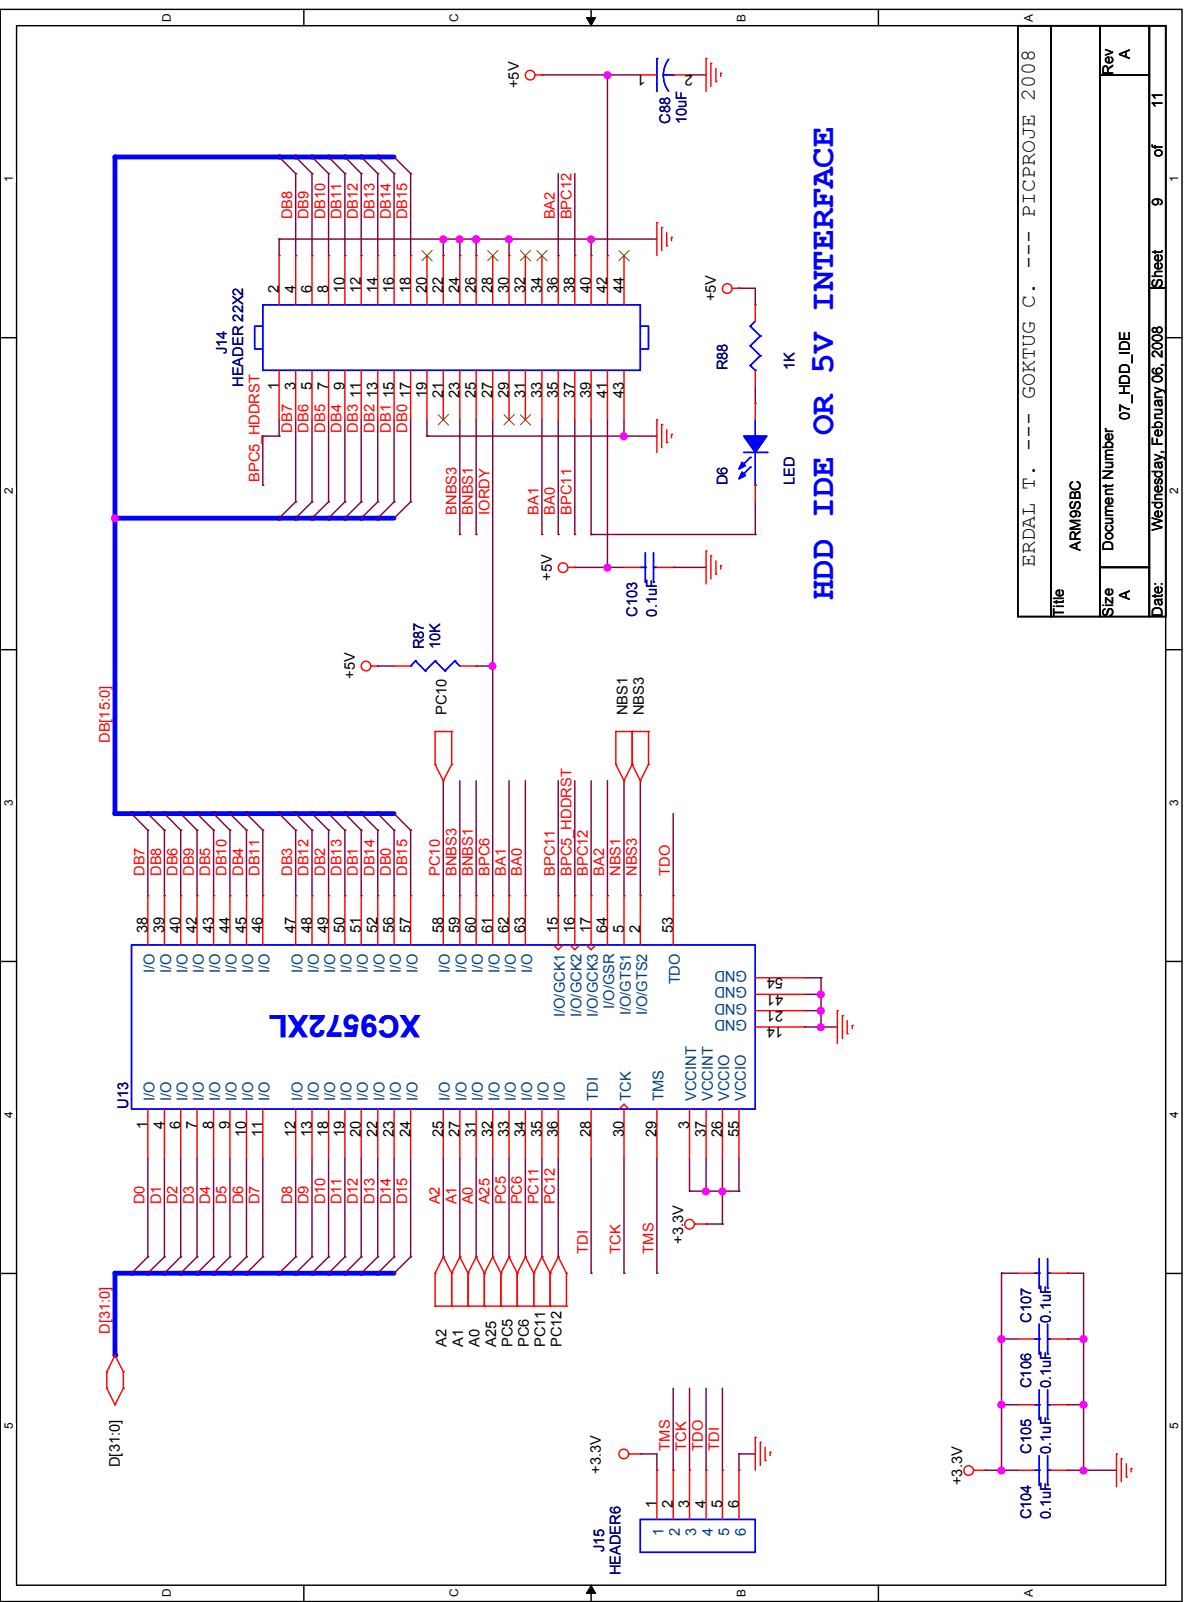
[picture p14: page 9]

Size Document Number Rev

HDD IDE OR 5V INTERFACE

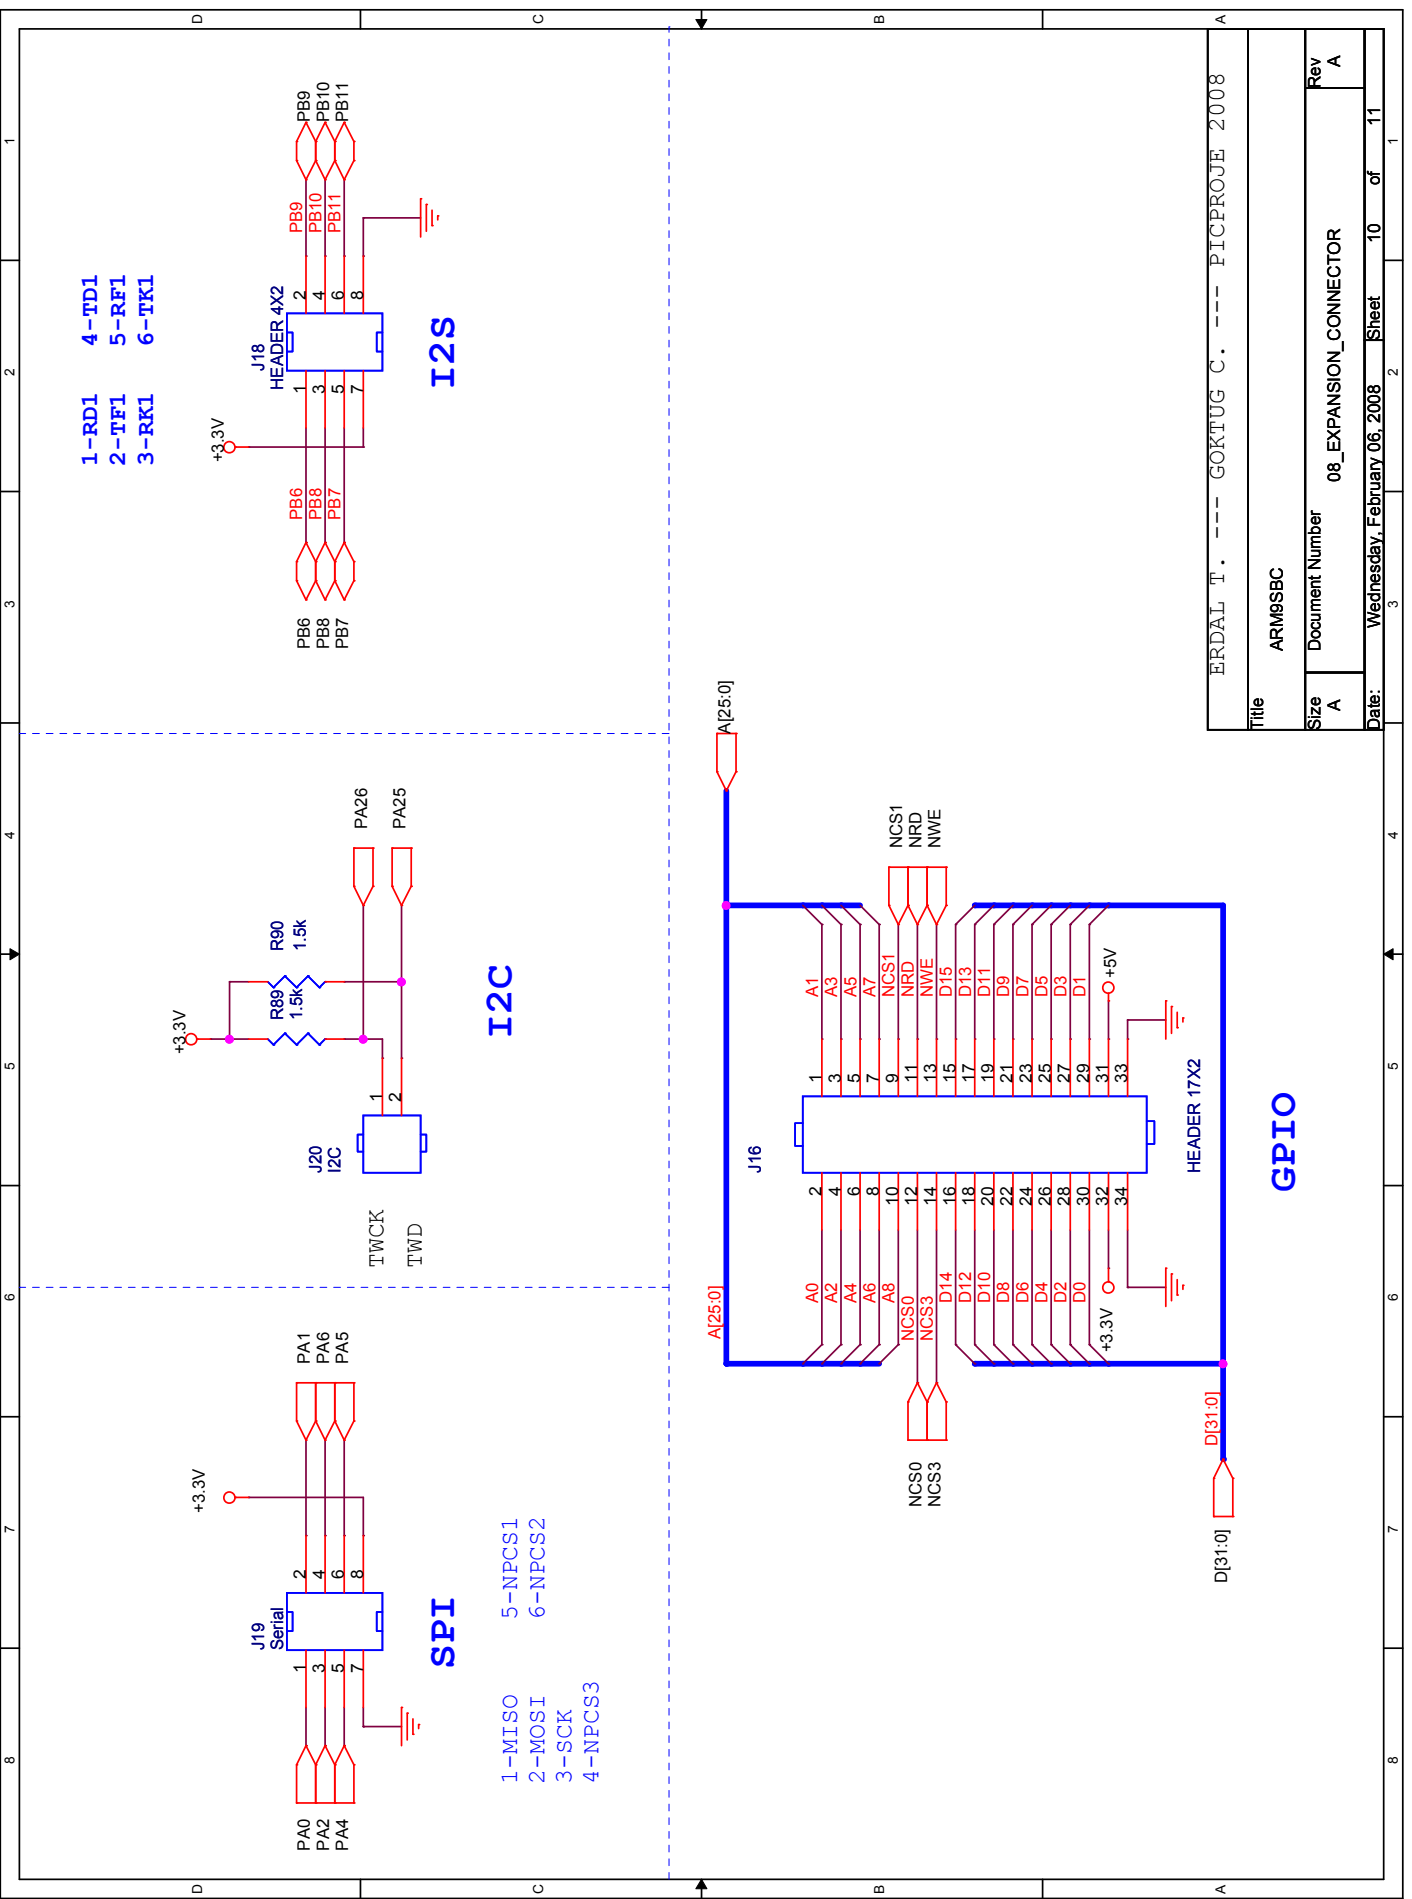
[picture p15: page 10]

Size Document Number Rev


Size Document Number Rev

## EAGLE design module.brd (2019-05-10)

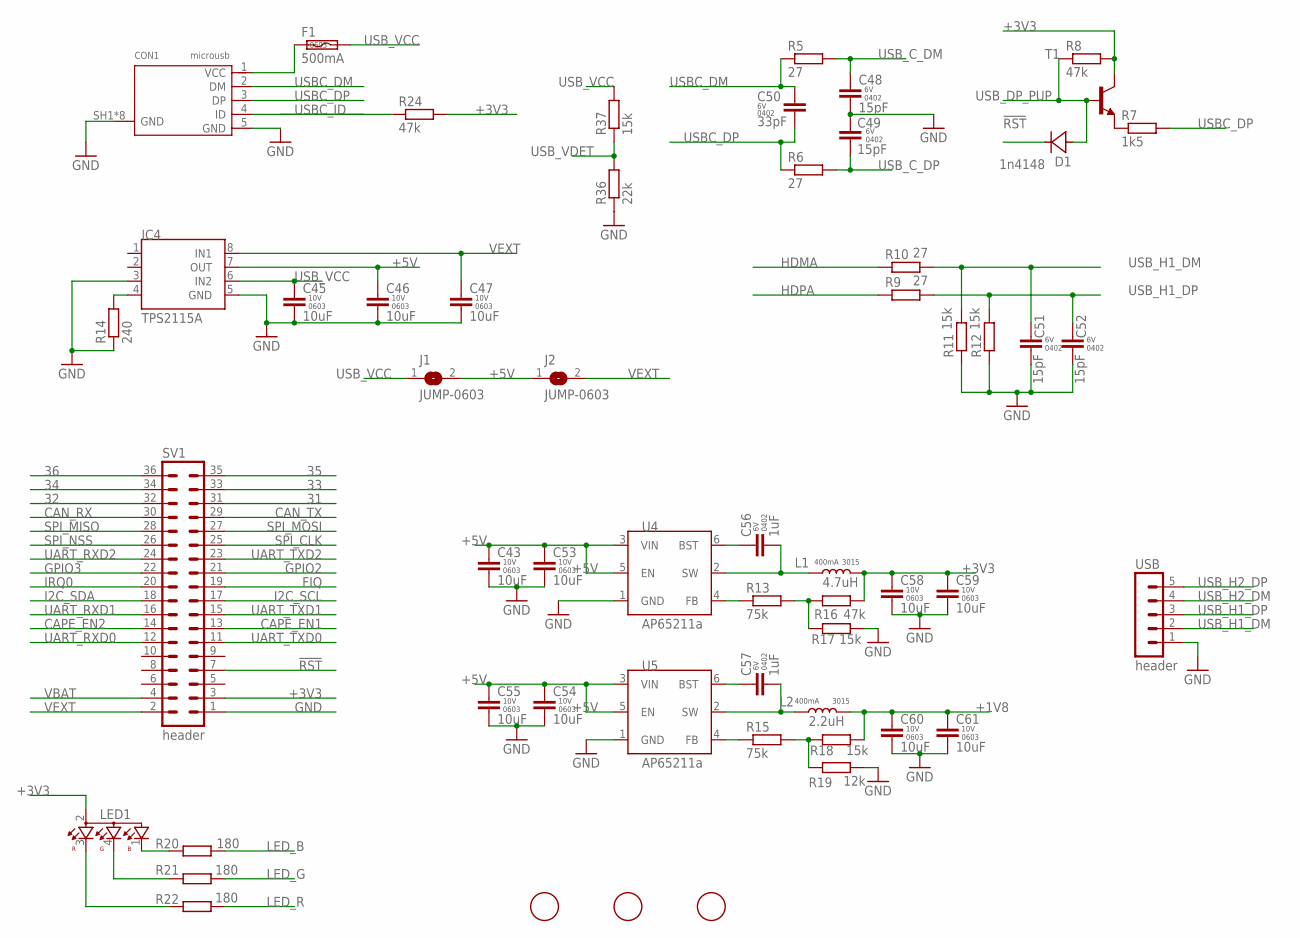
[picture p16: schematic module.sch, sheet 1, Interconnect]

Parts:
C43, C45, C46, C47, C53, C54, C55, C58, C59, C60, C61: 10uF; C0603
C48, C49, C51, C52: 15pF; C0402K
C50: 33pF; C0402K
C56, C57: 1uF; C0402K
CON1: microusb; 10118194
D1: 1n4148; SOD323
F1: 500mA; F0603
IC4: TPS2115A; TSSOP8
J1, J2: JUMP-0603; C0603
L1: 4.7uH; L3230M
L2: 2.2uH; L3230M
LED1: OSTB1204C1E; 321015RGB
R5, R6, R9, R10: 27; R0402
R7: 1k5; R0402
R8, R16, R24: 47k; R0402
R11, R12, R17, R18, R37: 15k; R0402
R13, R15: 75k; R0402
R14: 240; R0402
R19: 12k; R0402
R20, R21, R22: 180; R0402
R36: 22k; R0402
SV1: header; MA18-2
T1: MMBT2222ALT1-NPN-SOT23-BEC; SOT23-BEC
U4, U5: AP65211A; SOT95P280X110-6
U$1, U$2, U$3: FIDUCIAL; FIDUCIAL_1MM
USB: header; MA05-1

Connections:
31: SV1.31; also elsewhere on the board
32: SV1.32; also elsewhere on the board
33: SV1.33; also elsewhere on the board
34: SV1.34; also elsewhere on the board
35: SV1.35; also elsewhere on the board
36: SV1.36; also elsewhere on the board
!RST: D1.K (C), SV1.7; also elsewhere on the board
+1V8: C60.1, C61.1, L2.2, R18.2; also elsewhere on the board
+3V3: C58.1, C59.1, L1.2, LED1.2, R8.2, R16.2, R24.2, SV1.3, T1.C; also elsewhere on the board
+5V: C43.1, C46.1, C53.1, C54.1, C55.1, IC4.7 (OUT), J1.2, J2.1, U4.3 (VIN), U4.5 (EN), U5.3 (VIN), U5.5 (EN)
CAN_RX: SV1.30
CAN_TX: SV1.29
CAPE_EN1: SV1.13; also elsewhere on the board
CAPE_EN2: SV1.14; also elsewhere on the board
FIQ: SV1.19; also elsewhere on the board
GND: C43.2, C45.2, C46.2, C47.2, C48.2, C49.2, C51.2, C52.2, C53.2, C54.2, C55.2, C58.2, C59.2, C60.2, C61.2, CON1.5 (GND), CON1.SH1 (GND), CON1.SH2 (GND), CON1.SH3 (GND), CON1.SH4 (GND), CON1.SH5 (GND), CON1.SH6 (GND), CON1.SH7 (GND), CON1.SH8 (GND), IC4.3, IC4.5 (GND), R11.1, R12.1, R14.1, R17.2, R19.2, R36.1, SV1.1, U4.1 (GND), U5.1 (GND), USB.1; also elsewhere on the board
GPIO2: SV1.21; also elsewhere on the board
GPIO3: SV1.22; also elsewhere on the board
HDMA: R10.1; also elsewhere on the board
HDPA: R9.1; also elsewhere on the board
I2C_SCL: SV1.17; also elsewhere on the board
I2C_SDA: SV1.18; also elsewhere on the board
IRQ0: SV1.20; also elsewhere on the board
LED_B: R20.1; also elsewhere on the board
LED_G: R21.1; also elsewhere on the board
LED_R: R22.1; also elsewhere on the board
unnamed: C56.2, L1.1, U4.2 (SW)
unnamed: CON1.1 (VCC), F1.1
unnamed: IC4.4, R14.2
unnamed: C57.2, L2.1, U5.2 (SW)
unnamed: LED1.1, R20.2
unnamed: C56.1, U4.6 (BST)
unnamed: C57.1, U5.6 (BST)
unnamed: LED1.4, R21.2
unnamed: R15.1, U5.4 (FB)
unnamed: R7.1, T1.E
unnamed: R13.1, U4.4 (FB)
unnamed: R15.2, R18.1, R19.1
unnamed: R13.2, R16.1, R17.1
unnamed: LED1.3, R22.2
SPI_CLK: SV1.25; also elsewhere on the board
SPI_MISO: SV1.28; also elsewhere on the board
SPI_MOSI: SV1.27; also elsewhere on the board
SPI_NSS: SV1.26; also elsewhere on the board
UART_RXD0: SV1.12; also elsewhere on the board
UART_RXD1: SV1.16; also elsewhere on the board
UART_RXD2: SV1.24; also elsewhere on the board
UART_TXD0: SV1.11; also elsewhere on the board
UART_TXD1: SV1.15; also elsewhere on the board
UART_TXD2: SV1.23; also elsewhere on the board
USBC_DM: C50.1, CON1.2 (DM), R5.1
USBC_DP: C50.2, CON1.3 (DP), R6.1, R7.2
USBC_ID: CON1.4 (ID), R24.1; also elsewhere on the board
USB_C_DM: C48.1, R5.2; also elsewhere on the board
USB_C_DP: C49.1, R6.2; also elsewhere on the board
USB_DP_PUP: D1.A, R8.1, T1.B; also elsewhere on the board
USB_H1_DM: C51.1, R10.2, R11.2, USB.2
USB_H1_DP: C52.1, R9.2, R12.2, USB.3
USB_H2_DM: USB.4
USB_H2_DP: USB.5
USB_VCC: C45.1, F1.2, IC4.6 (IN2), J1.1, R37.2
USB_VDET: R36.2, R37.1; also elsewhere on the board
VBAT: SV1.4
VEXT: C47.1, IC4.8 (IN1), J2.2, SV1.2

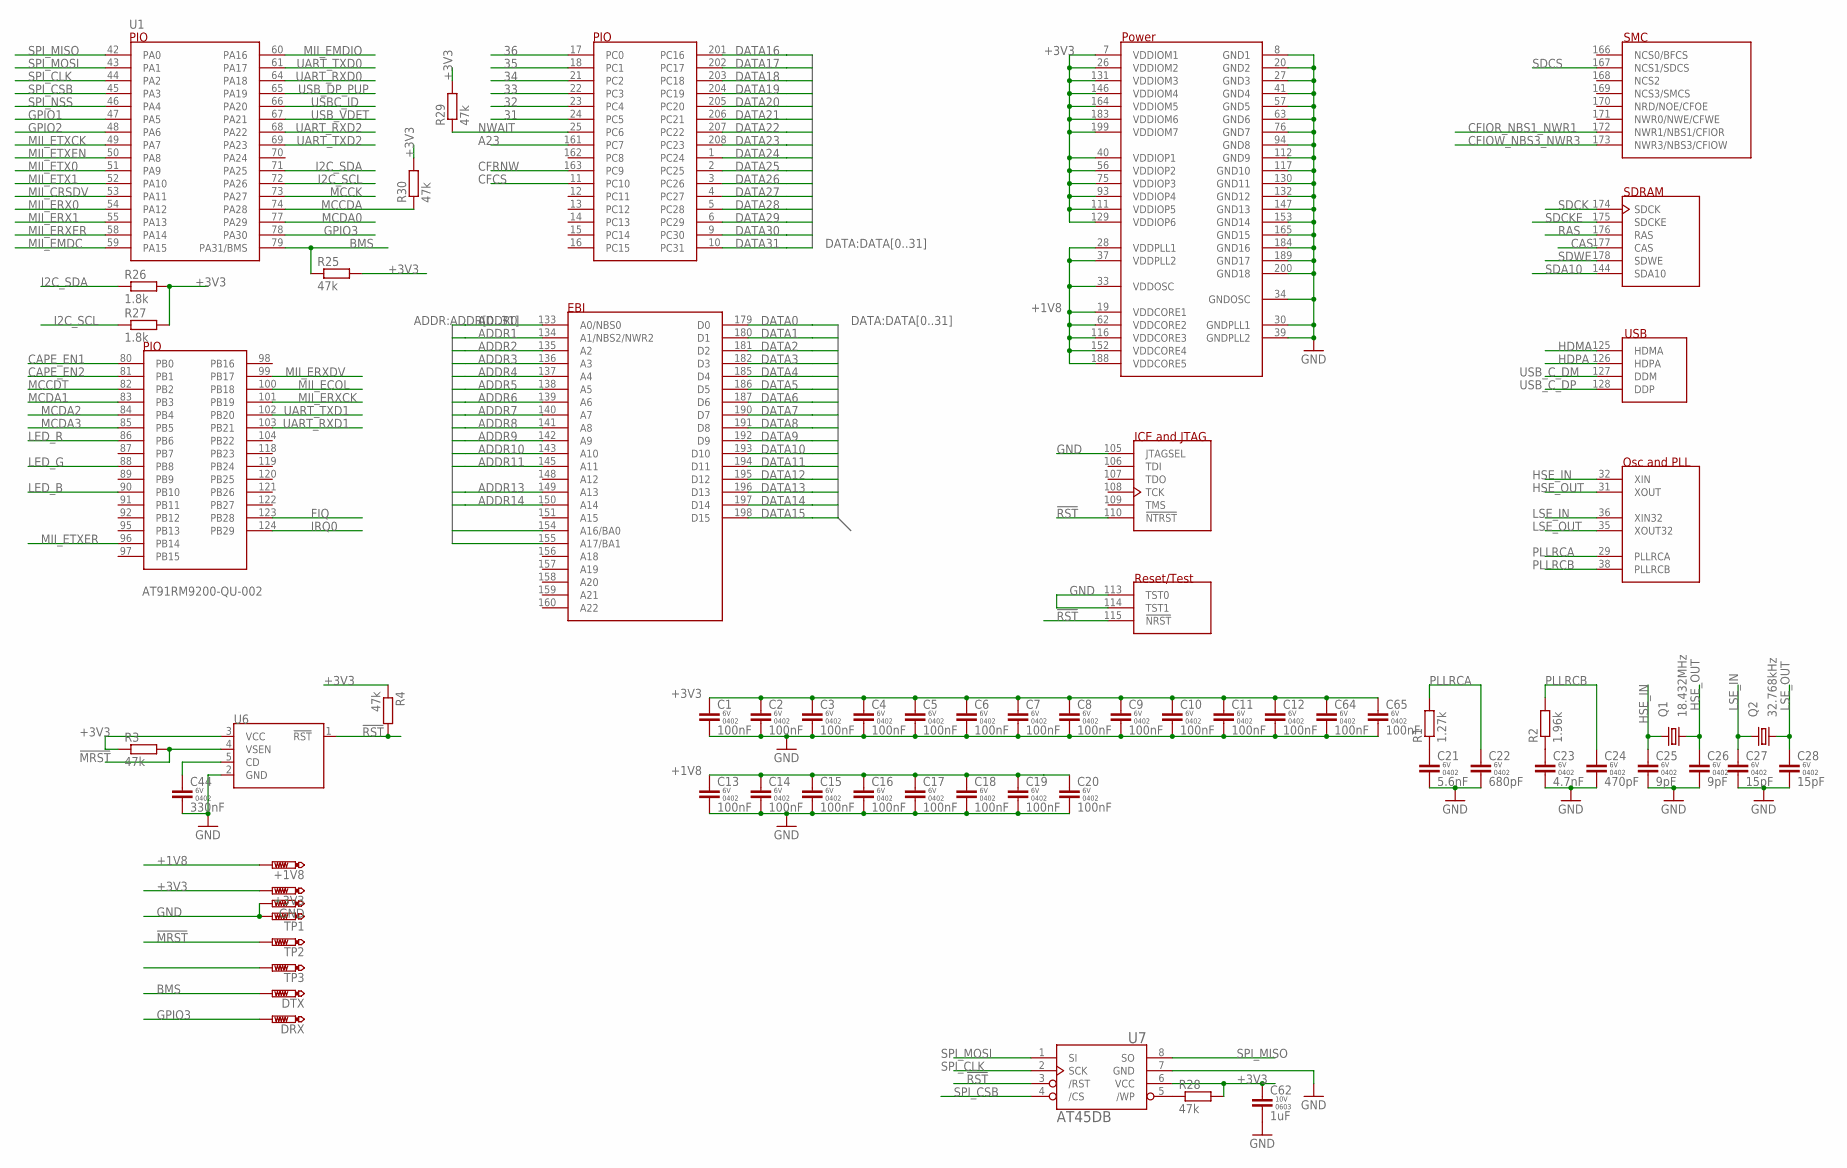
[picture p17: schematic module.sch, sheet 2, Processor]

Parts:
+1V8, +3V3: PTR1B1,27; B1,27
C1, C2, C3, C4, C5, C6, C7, C8, C9, C10, C11, C12, C13, C14, C15, C16, C17, C18, C19, C20, C64, C65: 100nF; C0402K
C21: 5.6nF; C0402K
C22: 680pF; C0402K
C23: 4.7nF; C0402K
C24: 470pF; C0402K
C25, C26: 9pF; C0402K
C27, C28: 15pF; C0402K
C44: 330nF; C0402K
C62: 1uF; C0603
DRX: PTR1B1,27; B1,27
DTX: PTR1B1,27; B1,27
GND: PTR1B1,27; B1,27
Q1: 18.432MHz; 3215
Q2: 32.768kHz; 3215
R1: 1.27k; R0402
R2: 1.96k; R0402
R3, R4, R25, R28, R29, R30: 47k; R0402
R26, R27: 1.8k; R0402
TP1, TP2, TP3: PTR1B1,27; B1,27
U1: AT91RM9200-QU-002; QFP50P3120X3120X410-208N
U6: STM1831; SOT95P280X100-5
U7: AT45DB-S; SO08-208

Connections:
31: U1.24 (PC5); also elsewhere on the board
32: U1.23 (PC4); also elsewhere on the board
33: U1.22 (PC3); also elsewhere on the board
34: U1.21 (PC2); also elsewhere on the board
35: U1.18 (PC1); also elsewhere on the board
36: U1.17 (PC0); also elsewhere on the board
!MRST: R3.2, TP2.TP, U6.4 (VSEN)
!RST: R4.2, U1.110 (!NTRST), U1.115 (!NRST), U6.1 (!RST), U7.3 (/RST); also elsewhere on the board
+1V8: +1V8.TP, C13.1, C14.1, C15.1, C16.1, C17.1, C18.1, C19.1, C20.1, U1.19 (VDDCORE1), U1.28 (VDDPLL1), U1.33 (VDDOSC), U1.37 (VDDPLL2), U1.62 (VDDCORE2), U1.116 (VDDCORE3), U1.152 (VDDCORE4), U1.188 (VDDCORE5); also elsewhere on the board
+3V3: +3V3.TP, C1.1, C2.1, C3.1, C4.1, C5.1, C6.1, C7.1, C8.1, C9.1, C10.1, C11.1, C12.1, C62.1, C64.1, C65.1, R3.1, R4.1, R25.2, R26.2, R27.2, R28.2, R29.2, R30.2, U1.7 (VDDIOM1), U1.26 (VDDIOM2), U1.40 (VDDIOP1), U1.56 (VDDIOP2), U1.75 (VDDIOP3), U1.93 (VDDIOP4), U1.111 (VDDIOP5), U1.129 (VDDIOP6), U1.131 (VDDIOM3), U1.146 (VDDIOM4), U1.164 (VDDIOM5), U1.183 (VDDIOM6), U1.199 (VDDIOM7), U6.3 (VCC), U7.6 (VCC); also elsewhere on the board
A23: U1.161 (PC7)
ADDR0: U1.133 (A0/NBS0); also elsewhere on the board
ADDR1: U1.134 (A1/NBS2/NWR2); also elsewhere on the board
ADDR2: U1.135 (A2); also elsewhere on the board
ADDR3: U1.136 (A3); also elsewhere on the board
ADDR4: U1.137 (A4); also elsewhere on the board
ADDR5: U1.138 (A5); also elsewhere on the board
ADDR6: U1.139 (A6); also elsewhere on the board
ADDR7: U1.140 (A7); also elsewhere on the board
ADDR8: U1.141 (A8); also elsewhere on the board
ADDR9: U1.142 (A9); also elsewhere on the board
ADDR10: U1.143 (A10); also elsewhere on the board
ADDR11: U1.145 (A11); also elsewhere on the board
ADDR13: U1.149 (A13); also elsewhere on the board
ADDR14: U1.150 (A14); also elsewhere on the board
ADDR16: U1.154 (A16/BA0); also elsewhere on the board
ADDR17: U1.155 (A17/BA1); also elsewhere on the board
BMS: DTX.TP, R25.1, U1.79 (PA31/BMS)
CAPE_EN1: U1.80 (PB0); also elsewhere on the board
CAPE_EN2: U1.81 (PB1); also elsewhere on the board
CAS: U1.177 (CAS); also elsewhere on the board
CFCS: U1.11 (PC10)
CFIOR_NBS1_NWR1: U1.172 (NWR1/NBS1/CFIOR); also elsewhere on the board
CFIOW_NBS3_NWR3: U1.173 (NWR3/NBS3/CFIOW); also elsewhere on the board
CFRNW: U1.163 (PC9)
DATA0: U1.179 (D0); also elsewhere on the board
DATA1: U1.180 (D1); also elsewhere on the board
DATA2: U1.181 (D2); also elsewhere on the board
DATA3: U1.182 (D3); also elsewhere on the board
DATA4: U1.185 (D4); also elsewhere on the board
DATA5: U1.186 (D5); also elsewhere on the board
DATA6: U1.187 (D6); also elsewhere on the board
DATA7: U1.190 (D7); also elsewhere on the board
DATA8: U1.191 (D8); also elsewhere on the board
DATA9: U1.192 (D9); also elsewhere on the board
DATA10: U1.193 (D10); also elsewhere on the board
DATA11: U1.194 (D11); also elsewhere on the board
DATA12: U1.195 (D12); also elsewhere on the board
DATA13: U1.196 (D13); also elsewhere on the board
DATA14: U1.197 (D14); also elsewhere on the board
DATA15: U1.198 (D15); also elsewhere on the board
DATA16: U1.201 (PC16); also elsewhere on the board
DATA17: U1.202 (PC17); also elsewhere on the board
DATA18: U1.203 (PC18); also elsewhere on the board
DATA19: U1.204 (PC19); also elsewhere on the board
DATA20: U1.205 (PC20); also elsewhere on the board
DATA21: U1.206 (PC21); also elsewhere on the board
DATA22: U1.207 (PC22); also elsewhere on the board
DATA23: U1.208 (PC23); also elsewhere on the board
DATA24: U1.1 (PC24); also elsewhere on the board
DATA25: U1.2 (PC25); also elsewhere on the board
DATA26: U1.3 (PC26); also elsewhere on the board
DATA27: U1.4 (PC27); also elsewhere on the board
DATA28: U1.5 (PC28); also elsewhere on the board
DATA29: U1.6 (PC29); also elsewhere on the board
DATA30: U1.9 (PC30); also elsewhere on the board
DATA31: U1.10 (PC31); also elsewhere on the board
FIQ: U1.123 (PB28); also elsewhere on the board
GND: C1.2, C2.2, C3.2, C4.2, C5.2, C6.2, C7.2, C8.2, C9.2, C10.2, C11.2, C12.2, C13.2, C14.2, C15.2, C16.2, C17.2, C18.2, C19.2, C20.2, C21.2, C22.2, C23.2, C24.2, C25.2, C26.2, C27.2, C28.2, C44.2, C62.2, C64.2, C65.2, GND.TP, TP1.TP, U1.8 (GND1), U1.20 (GND2), U1.27 (GND3), U1.30 (GNDPLL1), U1.34 (GNDOSC), U1.39 (GNDPLL2), U1.41 (GND4), U1.57 (GND5), U1.63 (GND6), U1.76 (GND7), U1.94 (GND8), U1.105 (JTAGSEL), U1.112 (GND9), U1.113 (TST0), U1.114 (TST1), U1.117 (GND10), U1.130 (GND11), U1.132 (GND12), U1.147 (GND13), U1.153 (GND14), U1.165 (GND15), U1.184 (GND16), U1.189 (GND17), U1.200 (GND18), U6.2 (GND), U7.7 (GND); also elsewhere on the board
GPIO1: U1.47 (PA5)
GPIO2: U1.48 (PA6); also elsewhere on the board
GPIO3: DRX.TP, U1.78 (PA30); also elsewhere on the board
HDMA: U1.125 (HDMA); also elsewhere on the board
HDPA: U1.126 (HDPA); also elsewhere on the board
HSE_IN: C25.1, Q1.1, U1.32 (XIN)
HSE_OUT: C26.1, Q1.3 (2), U1.31 (XOUT)
I2C_SCL: R27.1, U1.72 (PA26); also elsewhere on the board
I2C_SDA: R26.1, U1.71 (PA25); also elsewhere on the board
IRQ0: U1.124 (PB29); also elsewhere on the board
LED_B: U1.90 (PB10); also elsewhere on the board
LED_G: U1.88 (PB8); also elsewhere on the board
LED_R: U1.86 (PB6); also elsewhere on the board
LSE_IN: C27.1, Q2.1, U1.36 (XIN32)
LSE_OUT: C28.1, Q2.2, U1.35 (XOUT32)
MCCDA: R30.1, U1.74 (PA28); also elsewhere on the board
MCCDT: U1.82 (PB2); also elsewhere on the board
MCCK: U1.73 (PA27); also elsewhere on the board
MCDA0: U1.77 (PA29); also elsewhere on the board
MCDA1: U1.83 (PB3); also elsewhere on the board
MCDA2: U1.84 (PB4); also elsewhere on the board
MCDA3: U1.85 (PB5); also elsewhere on the board
MII_CRSDV: U1.53 (PA11); also elsewhere on the board
MII_ECOL: U1.100 (PB18)
MII_EMDC: U1.59 (PA15); also elsewhere on the board
MII_EMDIO: U1.60 (PA16); also elsewhere on the board
MII_ERX0: U1.54 (PA12); also elsewhere on the board
MII_ERX1: U1.55 (PA13); also elsewhere on the board
MII_ERXCK: U1.101 (PB19)
MII_ERXDV: U1.99 (PB17)
MII_ERXER: U1.58 (PA14); also elsewhere on the board
MII_ETX0: U1.51 (PA9); also elsewhere on the board
MII_ETX1: U1.52 (PA10); also elsewhere on the board
MII_ETXCK: U1.49 (PA7); also elsewhere on the board
MII_ETXEN: U1.50 (PA8); also elsewhere on the board
MII_ETXER: U1.96 (PB14)
unnamed: C21.1, R1.1
unnamed: C23.1, R2.1
unnamed: R28.1, U7.5 (/WP)
unnamed: C44.1, U6.5 (CD)
NWAIT: R29.1, U1.25 (PC6)
PLLRCA: C22.1, R1.2, U1.29 (PLLRCA)
PLLRCB: C24.1, R2.2, U1.38 (PLLRCB)
RAS: U1.176 (RAS); also elsewhere on the board
SDA10: U1.144 (SDA10); also elsewhere on the board
SDCK: U1.174 (SDCK); also elsewhere on the board
SDCKE: U1.175 (SDCKE); also elsewhere on the board
SDCS: U1.167 (NCS1/SDCS); also elsewhere on the board
SDWE: U1.178 (SDWE); also elsewhere on the board
SPI_CLK: U1.44 (PA2), U7.2 (SCK); also elsewhere on the board
SPI_CSB: U1.45 (PA3), U7.4 (/CS)
SPI_MISO: U1.42 (PA0), U7.8 (SO); also elsewhere on the board
SPI_MOSI: U1.43 (PA1), U7.1 (SI); also elsewhere on the board
SPI_NSS: U1.46 (PA4); also elsewhere on the board
UART_RXD0: U1.64 (PA18); also elsewhere on the board
UART_RXD1: U1.103 (PB21); also elsewhere on the board
UART_RXD2: U1.68 (PA22); also elsewhere on the board
UART_TXD0: U1.61 (PA17); also elsewhere on the board
UART_TXD1: U1.102 (PB20); also elsewhere on the board
UART_TXD2: U1.69 (PA23); also elsewhere on the board
USBC_ID: U1.66 (PA20); also elsewhere on the board
USB_C_DM: U1.127 (DDM); also elsewhere on the board
USB_C_DP: U1.128 (DDP); also elsewhere on the board
USB_DP_PUP: U1.65 (PA19); also elsewhere on the board
USB_VDET: U1.67 (PA21); also elsewhere on the board

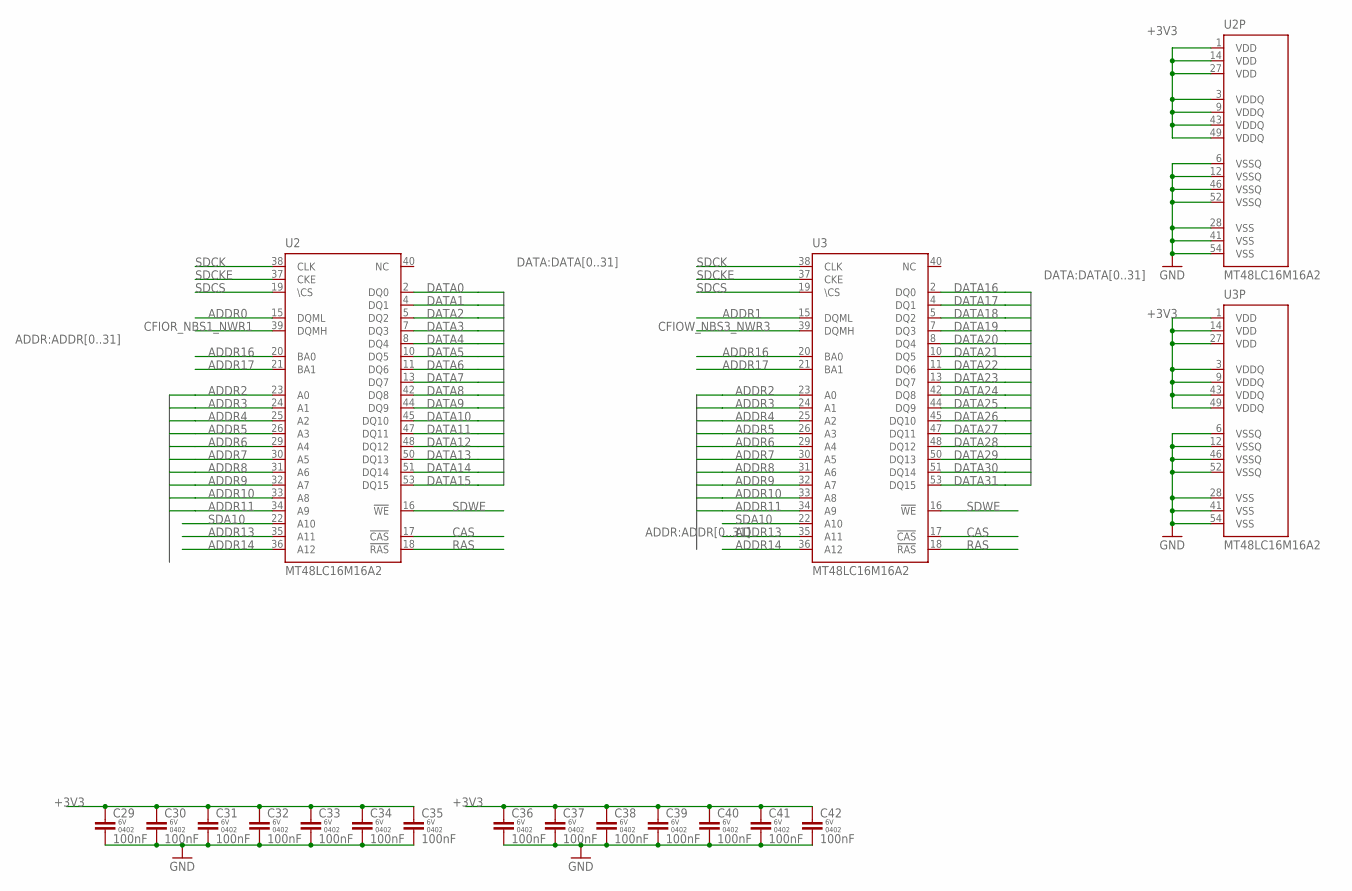
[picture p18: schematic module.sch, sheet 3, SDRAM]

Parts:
C29, C30, C31, C32, C33, C34, C35, C36, C37, C38, C39, C40, C41, C42: 100nF; C0402K
U2, U3: MT48LC16M16A2; TSOP54-400

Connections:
+3V3: C29.1, C30.1, C31.1, C32.1, C33.1, C34.1, C35.1, C36.1, C37.1, C38.1, C39.1, C40.1, C41.1, C42.1, U2.1 (VDD), U2.3 (VDDQ), U2.9 (VDDQ), U2.14 (VDD), U2.27 (VDD), U2.43 (VDDQ), U2.49 (VDDQ), U3.1 (VDD), U3.3 (VDDQ), U3.9 (VDDQ), U3.14 (VDD), U3.27 (VDD), U3.43 (VDDQ), U3.49 (VDDQ); also elsewhere on the board
ADDR0: U2.15 (DQML); also elsewhere on the board
ADDR1: U3.15 (DQML); also elsewhere on the board
ADDR2: U2.23 (A0), U3.23 (A0); also elsewhere on the board
ADDR3: U2.24 (A1), U3.24 (A1); also elsewhere on the board
ADDR4: U2.25 (A2), U3.25 (A2); also elsewhere on the board
ADDR5: U2.26 (A3), U3.26 (A3); also elsewhere on the board
ADDR6: U2.29 (A4), U3.29 (A4); also elsewhere on the board
ADDR7: U2.30 (A5), U3.30 (A5); also elsewhere on the board
ADDR8: U2.31 (A6), U3.31 (A6); also elsewhere on the board
ADDR9: U2.32 (A7), U3.32 (A7); also elsewhere on the board
ADDR10: U2.33 (A8), U3.33 (A8); also elsewhere on the board
ADDR11: U2.34 (A9), U3.34 (A9); also elsewhere on the board
ADDR13: U2.35 (A11), U3.35 (A11); also elsewhere on the board
ADDR14: U2.36 (A12), U3.36 (A12); also elsewhere on the board
ADDR16: U2.20 (BA0), U3.20 (BA0); also elsewhere on the board
ADDR17: U2.21 (BA1), U3.21 (BA1); also elsewhere on the board
CAS: U2.17 (!CAS), U3.17 (!CAS); also elsewhere on the board
CFIOR_NBS1_NWR1: U2.39 (DQMH); also elsewhere on the board
CFIOW_NBS3_NWR3: U3.39 (DQMH); also elsewhere on the board
DATA0: U2.2 (DQ0); also elsewhere on the board
DATA1: U2.4 (DQ1); also elsewhere on the board
DATA2: U2.5 (DQ2); also elsewhere on the board
DATA3: U2.7 (DQ3); also elsewhere on the board
DATA4: U2.8 (DQ4); also elsewhere on the board
DATA5: U2.10 (DQ5); also elsewhere on the board
DATA6: U2.11 (DQ6); also elsewhere on the board
DATA7: U2.13 (DQ7); also elsewhere on the board
DATA8: U2.42 (DQ8); also elsewhere on the board
DATA9: U2.44 (DQ9); also elsewhere on the board
DATA10: U2.45 (DQ10); also elsewhere on the board
DATA11: U2.47 (DQ11); also elsewhere on the board
DATA12: U2.48 (DQ12); also elsewhere on the board
DATA13: U2.50 (DQ13); also elsewhere on the board
DATA14: U2.51 (DQ14); also elsewhere on the board
DATA15: U2.53 (DQ15); also elsewhere on the board
DATA16: U3.2 (DQ0); also elsewhere on the board
DATA17: U3.4 (DQ1); also elsewhere on the board
DATA18: U3.5 (DQ2); also elsewhere on the board
DATA19: U3.7 (DQ3); also elsewhere on the board
DATA20: U3.8 (DQ4); also elsewhere on the board
DATA21: U3.10 (DQ5); also elsewhere on the board
DATA22: U3.11 (DQ6); also elsewhere on the board
DATA23: U3.13 (DQ7); also elsewhere on the board
DATA24: U3.42 (DQ8); also elsewhere on the board
DATA25: U3.44 (DQ9); also elsewhere on the board
DATA26: U3.45 (DQ10); also elsewhere on the board
DATA27: U3.47 (DQ11); also elsewhere on the board
DATA28: U3.48 (DQ12); also elsewhere on the board
DATA29: U3.50 (DQ13); also elsewhere on the board
DATA30: U3.51 (DQ14); also elsewhere on the board
DATA31: U3.53 (DQ15); also elsewhere on the board
GND: C29.2, C30.2, C31.2, C32.2, C33.2, C34.2, C35.2, C36.2, C37.2, C38.2, C39.2, C40.2, C41.2, C42.2, U2.6 (VSSQ), U2.12 (VSSQ), U2.28 (VSS), U2.41 (VSS), U2.46 (VSSQ), U2.52 (VSSQ), U2.54 (VSS), U3.6 (VSSQ), U3.12 (VSSQ), U3.28 (VSS), U3.41 (VSS), U3.46 (VSSQ), U3.52 (VSSQ), U3.54 (VSS); also elsewhere on the board
RAS: U2.18 (!RAS), U3.18 (!RAS); also elsewhere on the board
SDA10: U2.22 (A10), U3.22 (A10); also elsewhere on the board
SDCK: U2.38 (CLK), U3.38 (CLK); also elsewhere on the board
SDCKE: U2.37 (CKE), U3.37 (CKE); also elsewhere on the board
SDCS: U2.19 (\CS), U3.19 (\CS); also elsewhere on the board
SDWE: U2.16 (!WE), U3.16 (!WE); also elsewhere on the board

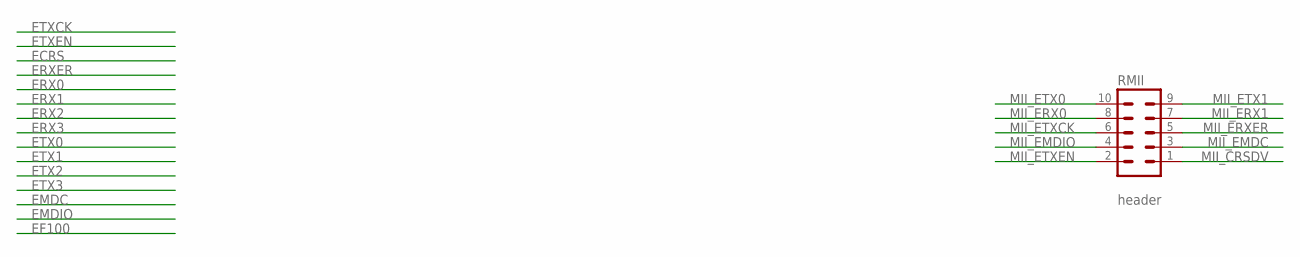
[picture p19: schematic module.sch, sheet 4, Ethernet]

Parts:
RMII: header; MA05-2

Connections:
MII_CRSDV: RMII.1; also elsewhere on the board
MII_EMDC: RMII.3; also elsewhere on the board
MII_EMDIO: RMII.4; also elsewhere on the board
MII_ERX0: RMII.8; also elsewhere on the board
MII_ERX1: RMII.7; also elsewhere on the board
MII_ERXER: RMII.5; also elsewhere on the board
MII_ETX0: RMII.10; also elsewhere on the board
MII_ETX1: RMII.9; also elsewhere on the board
MII_ETXCK: RMII.6; also elsewhere on the board
MII_ETXEN: RMII.2; also elsewhere on the board

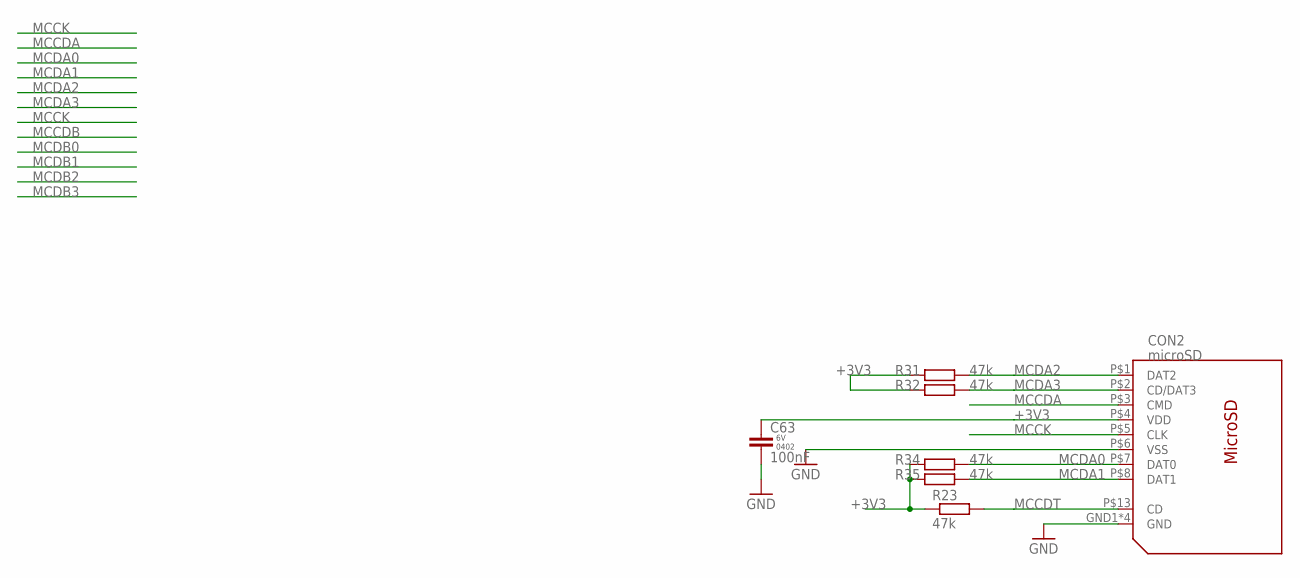
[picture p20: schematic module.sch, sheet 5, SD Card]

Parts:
C63: 100nF; C0402K
CON2: microSD; 112J
R23, R31, R32, R34, R35: 47k; R0402

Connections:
+3V3: C63.1, CON2.P$4 (VDD), R23.1, R31.1, R32.1, R34.1, R35.1; also elsewhere on the board
GND: C63.2, CON2.GND1 (GND), CON2.GND2 (GND), CON2.GND3 (GND), CON2.GND4 (GND), CON2.P$6 (VSS); also elsewhere on the board
MCCDA: CON2.P$3 (CMD); also elsewhere on the board
MCCDT: CON2.P$13 (CD), R23.2; also elsewhere on the board
MCCK: CON2.P$5 (CLK); also elsewhere on the board
MCDA0: CON2.P$7 (DAT0), R34.2; also elsewhere on the board
MCDA1: CON2.P$8 (DAT1), R35.2; also elsewhere on the board
MCDA2: CON2.P$1 (DAT2), R31.2; also elsewhere on the board
MCDA3: CON2.P$2 (CD/DAT3), R32.2; also elsewhere on the board

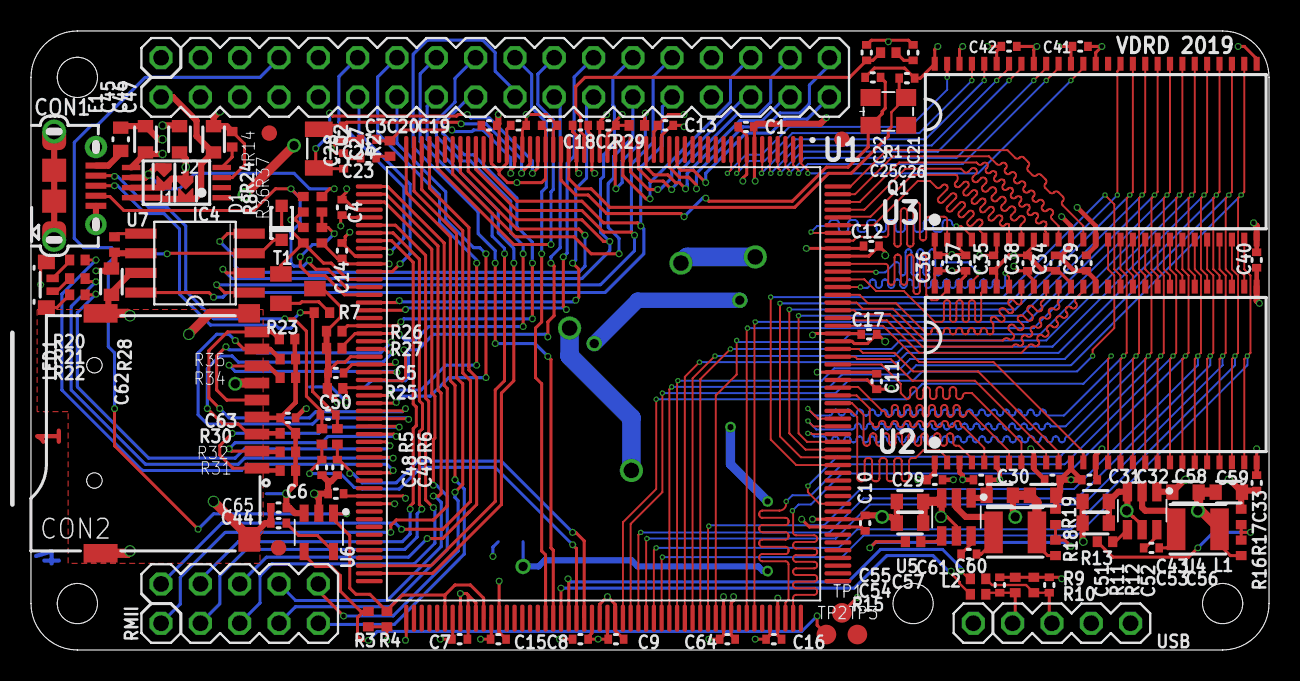
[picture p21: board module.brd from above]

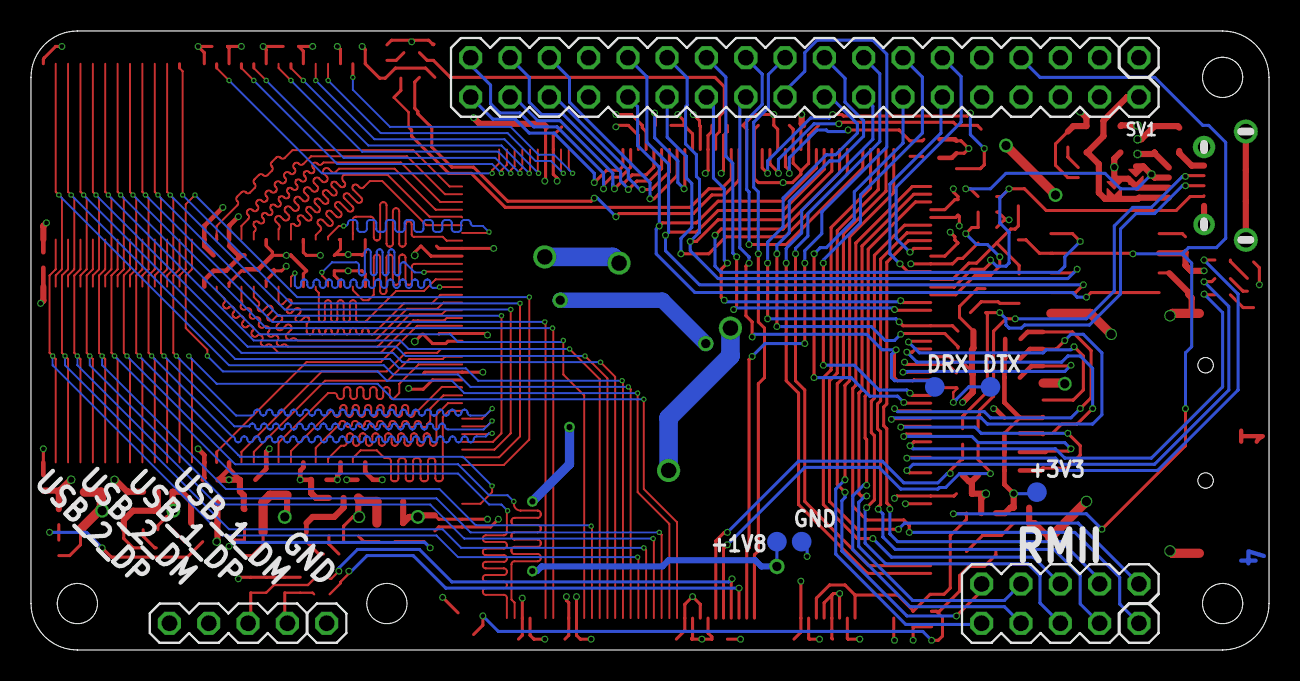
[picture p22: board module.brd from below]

Board: 4 copper layers, 80.0 x 40.0 mm, 135 parts (6 on the bottom side), 147 nets.

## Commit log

2019-04-08 repo bringup
    [module.brd, module.sch]
2019-04-08 added gitignore
    [module.brd, module.sch]
2019-04-08 defined major connections
    [module.brd, module.sch]
2019-04-09 added connectors
    [module.brd, module.sch]
2019-04-09 added bga variant
    [module_bga.brd, module_bga.sch]
2019-04-10 added bga sdram
    [module_bga.brd, module_bga.sch]
2019-04-10 finished sdram routing
    [module.brd, module_bga.brd, module_bga.sch]
2019-04-11 updated schematic
    [module.brd]
2019-04-12 small fixes
    [module.brd, module.sch]
2019-04-12 defined pinout
    [module.brd, module.sch]
2019-04-12 refined board shape
    [module.brd, module.sch]
2019-04-14 added power stages
    [module.brd, module.sch]
2019-04-15 updated footprint positions
    [module.brd]
2019-04-15 added usb connections
    [module.brd, module.sch]
2019-04-15 added power plane
    [module.brd, module.sch]
2019-04-17 added documentation
    [module.brd]
2019-04-17 another board example
2019-04-19 board: bms pull-up for proper boot
    [module.brd, module.sch]
2019-04-19 board: update render
    [module.brd, module.sch]
2019-04-19 board: remove bga variant
    [module_bga.brd, module_bga.sch]
2019-04-19 board: add i2c pullup
    [module.brd, module.sch]
2019-04-21 board: define usb host connector interface
    [module.brd, module.sch]
2019-04-21 schematic: define usb host nets
    [module.brd, module.sch]
2019-04-21 layout: preliminary usb routing
    [module.brd]
2019-04-22 board: add missing pwr supply pin
    [module.brd, module.sch]
2019-04-22 board: removed button
    [module.brd, module.sch]
2019-04-22 schematic: added gpio connections
    [module.brd, module.sch]
2019-04-22 board: rmii connector 1st draft
    [module.brd, module.sch]
2019-04-24 layout: updated connectors
    [module.brd, module.sch]
2019-04-24 layout: trace routing and optimisation
    [module.brd]
2019-04-24 schematic: defined led connections
    [module.brd, module.sch]
2019-04-24 board: added missing pull-up for dataflash
    [module.brd, module.sch]
2019-04-24 layout: initial rmii routing
    [module.brd, module.sch]
2019-04-25 board: verified agains schematic checklist
    [module.brd, module.sch]
2019-04-25 layout: clear routing errors
    [module.brd]
2019-04-25 layout: optimised descriptor placement
    [module.brd]
2019-04-25 layout: fixed dataflash footprint
    [module.brd, module.sch]
2019-04-25 layout: added pinout descriptors
    [module.brd]
2019-04-25 board: added fiducials
    [module.brd, module.sch]
2019-04-25 layout: fanout main connector
    [module.brd, module.sch]
2019-04-25 added manual selection for power source
    [module.brd, module.sch]
2019-04-25 layout: various traces routed'
    [module.brd, module.sch]
2019-04-25 layout: defined usb support components
    [module.brd, module.sch]
2019-04-25 layout: signal routing
    [module.brd, module.sch]
2019-04-26 layout: small fixes
    [module.brd]
2019-04-26 board: exported bom
    [module.brd, module.sch]
2019-05-03 schematic: added values for step-down
    [module.brd, module.sch]
2019-05-07 finished board rev1
    [module.brd, module.sch]
2019-05-10 project: updated documentation
    [module.brd, module.sch]
2019-05-10 project: small fixes
    [module.brd, module.sch]
2019-05-10 board: added testpoints
    [module.brd, module.sch]
2019-05-10 board: matched JLC7628 stackup
    [module.brd]
